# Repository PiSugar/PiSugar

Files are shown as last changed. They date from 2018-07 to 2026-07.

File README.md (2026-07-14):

<p align="center">
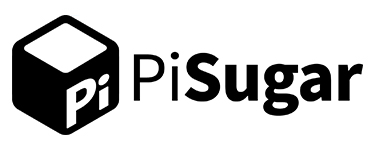
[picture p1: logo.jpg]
  
</p>

English | [简体中文](./README.zh-CN.md)

#### Hackaday Project Page

https://hackaday.io/project/164733-pisugar-battery-for-raspberry-pi-zero

#### Official Store:

<a href="https://shop.pisugar.com/?ref=github" target="_blank">PiSugar Kitchen</a> 

#### Tindie Store



#### PiSugar3 on Amazon:
<a href="https://www.amazon.com/dp/B0H5JMWJJ6" target="_blank">US</a> 
<a href="https://www.amazon.co.uk/dp/B09QS12N1W" target="_blank">UK</a> 
<a href="https://www.amazon.de/dp/B09QS12N1W" target="_blank">Germany</a> 
<a href="https://www.amazon.fr/dp/B09QS12N1W?ref=myi_title_dp" target="_blank">France</a> 
<a href="https://www.amazon.com.au/dp/B0CXX7X9X7" target="_blank">Australia</a> 
<a href="http://www.amazon.co.jp/dp/B09QRQPWYC?ref=myi_title_dp" target="_blank">Japan</a> 

#### PiSugar3 Plus on Amazon:
<a href="https://www.amazon.com/dp/B0H51CW3Q5" target="_blank">US</a> 
<a href="https://www.amazon.co.uk/dp/B09QRS666Y" target="_blank">UK</a> 
<a href="https://www.amazon.de/dp/B09QRS666Y" target="_blank">Germany</a> 
<a href="https://www.amazon.fr/dp/B09QRS666Y?ref=myi_title_dp" target="_blank">France</a>  
<a href="https://www.amazon.com.au/dp/B09QRS666Y?ref=myi_title_dp" target="_blank">Australia</a> 
<a href="https://www.amazon.co.jp/dp/B09QRY2KNG?ref=myi_title_dp" target="_blank">Japan</a> 

#### PiSugar3 Air on Amazon:
<a href="https://www.amazon.com/dp/B0H4Z5XK7F" target="_blank">US</a> 

#### PiSugar2 on Amazon:
<a href="https://www.amazon.com/dp/B08D678XPR" target="_blank">US</a> 
<a href="https://www.amazon.co.uk/dp/B08D678XPR" target="_blank">UK</a> 
<a href="https://www.amazon.de/dp/B08D678XPR" target="_blank">Germany</a> 
<a href="https://www.amazon.fr/dp/B08D678XPR" target="_blank">France</a>
<a href="https://www.amazon.com.au/dp/B08D678XPR?ref=myi_title_dp" target="_blank">Australia</a>  
<a href="https://www.amazon.co.jp/dp/B08D678XPR" target="_blank">Japan</a>

#### PiSugar2 Pro(Plus) on Amazon:
<a href="https://www.amazon.com/dp/B08D8PPCKN" target="_blank">US</a> 
<a href="https://www.amazon.co.uk/dp/B08D8PPCKN" target="_blank">UK</a> 
<a href="https://www.amazon.de/dp/B08D8PPCKN" target="_blank">Germany</a> 
<a href="https://www.amazon.fr/dp/B08D8PPCKN" target="_blank">France</a> 
<a href="https://www.amazon.com.au/dp/B08D8PPCKN?ref=myi_title_dp" target="_blank">Australia</a>  
<a href="https://www.amazon.co.jp/dp/B08D8PPCKN" target="_blank">Japan</a> 

#### PiSugarS on Amazon:
<a href="https://www.amazon.com/dp/B0H4VCS6CF" target="_blank">US</a> 

#### PiSugarS Plus on Amazon:
<a href="https://www.amazon.com/dp/B0H4TY3KCN" target="_blank">US</a> 

#### Product Wiki

[PiSugar Wiki](https://docs.pisugar.com)

## Why We Make PiSugar

In the last few months, we have been working on projects base on Pi zero. It always comes to my mind that why we choose this tiny thing, to build a new portable product.

We believe perfect size will completely change the way we think.
We also believe in delicacy and better experience, which are essential for electronic circuit board.

After trying a number of power supply solutions, we found that none of them is elegent enough.
So we decide make it by ourselves. 

We call it PiSugar PowerPack — a power module specially designed for raspberry pi.

PiSugar Demo

## Features

#### Perfect Size
The sizes of circuit board and bettery perfectly match raspberry pi zero. You can easy put your prototypes in small cases.

#### Easy to Install
Install in one minute. No need for welding. Friendly for beginners.

#### USB Charging
Charge via micro USB port. Also you can charge when it is running a raspberry pi zero.

#### On-board Switch
One tap to turn on, dual taps to turn it off. No need to detach.

#### Place It Anywhere
With iron sheets inside, you can place your pi zero anywhere with magnet.

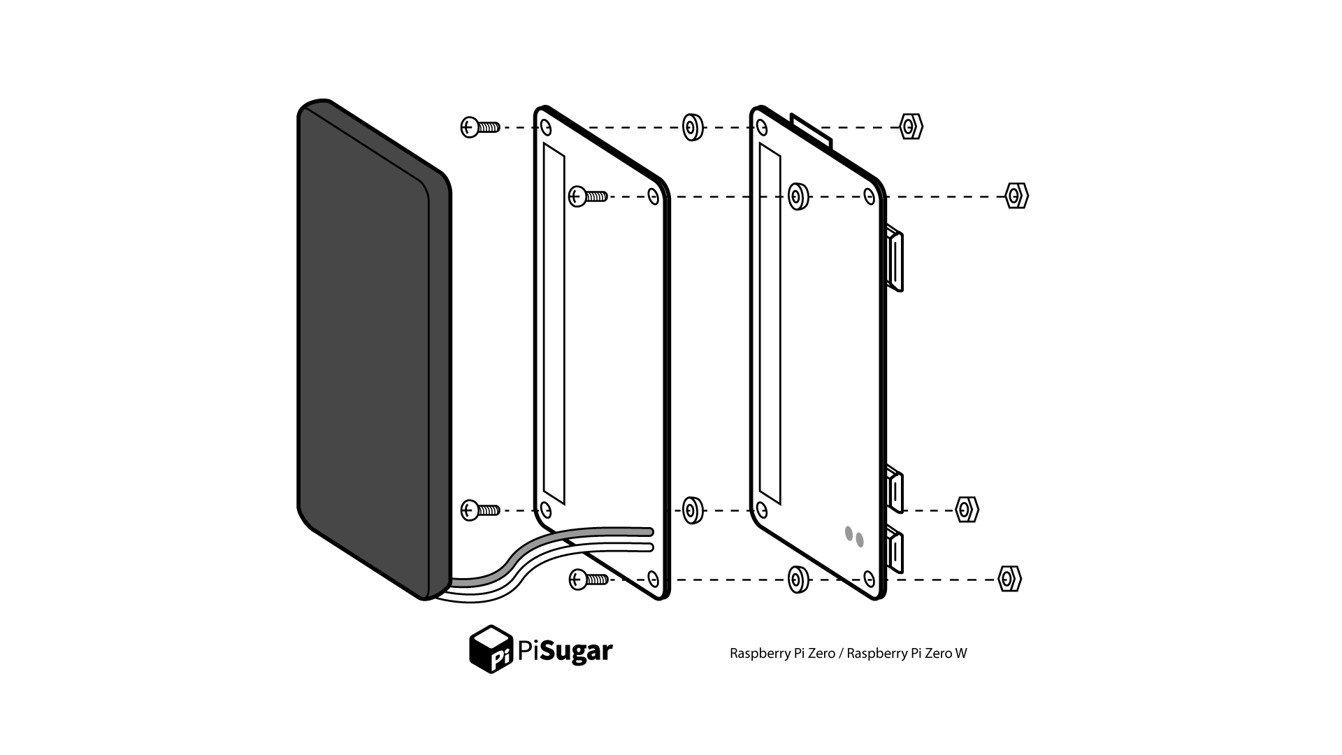
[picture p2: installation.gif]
Easy to install

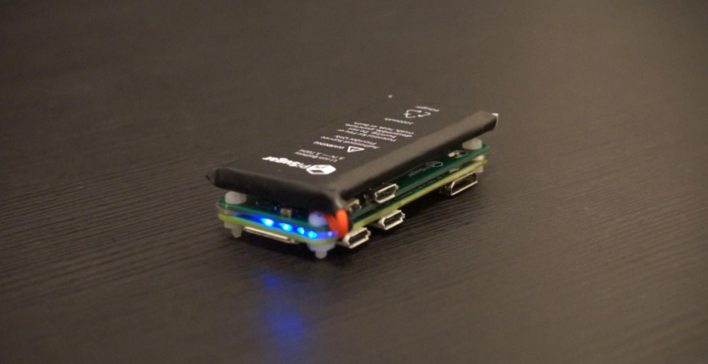
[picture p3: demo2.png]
PiSugar Demo


## PiSugar Case

Link to PiSugar Case: https://github.com/PiSugar/PiSugar/tree/master/model

Link to PiSugar2 Case: https://github.com/PiSugar/PiSugar/tree/master/model2

Link to PiSugar3 Case: https://github.com/PiSugar/PiSugar/tree/master/model3

Link to PHAT Caps: https://github.com/PiSugar/pisugar-case-pihat-cap

PiSugar Caps

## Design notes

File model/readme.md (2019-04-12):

# PiSugar Case

PiSugar Logo

#### PiSugar Case 3D-printed Models

[简体中文](https://github.com/PiSugar/PiSugar/tree/master/model/readme.zh-CN.md) | English

Files included:

- pisugar_case_shell （use with 900mAh battery）

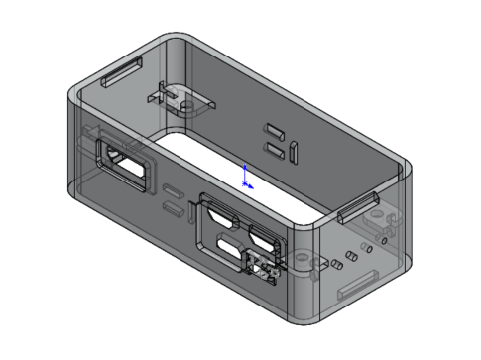
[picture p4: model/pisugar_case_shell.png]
pisugar_case_shell


- pisugar_case_shell_xl （use with 1200mAh battery）

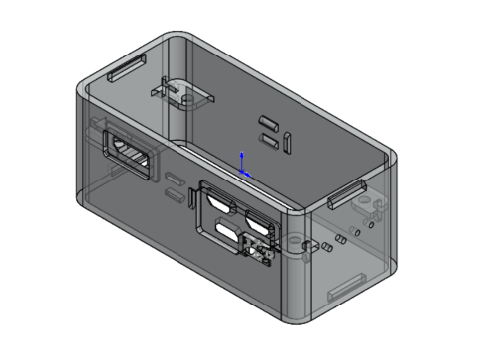
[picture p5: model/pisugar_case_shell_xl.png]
pisugar_case_shell_xl


- pisugar_case_common_cap （common cap for both top and bottom）

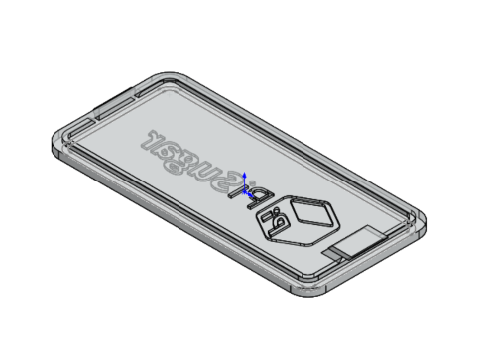
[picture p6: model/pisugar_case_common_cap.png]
pisugar_case_common_cap


- pisugar_case_pin_cap （cap with GPIO opening）

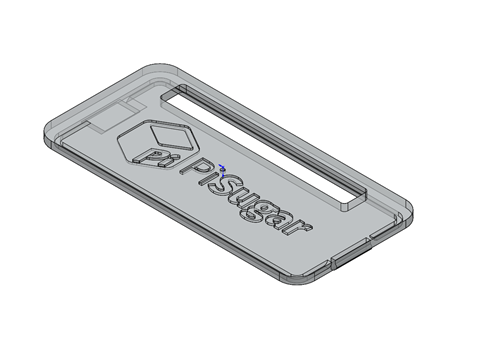
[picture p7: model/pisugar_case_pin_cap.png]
pisugar_case_pin_cap


- pisugar_case_top_cap （cap with 2 screw holes, should use with 1cm standoff）

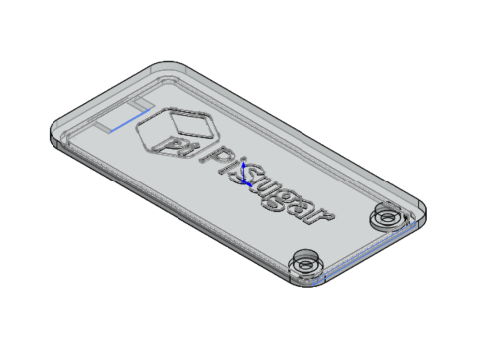
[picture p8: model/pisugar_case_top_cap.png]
pisugar_case_top_cap


- pisugar_case_button （single button）

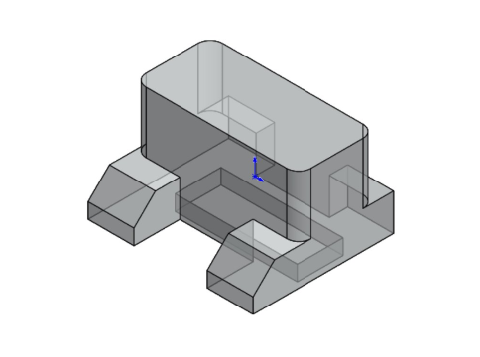
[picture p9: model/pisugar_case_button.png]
pisugar_case_button


- pisugar_case_button_comp (8 buttons)

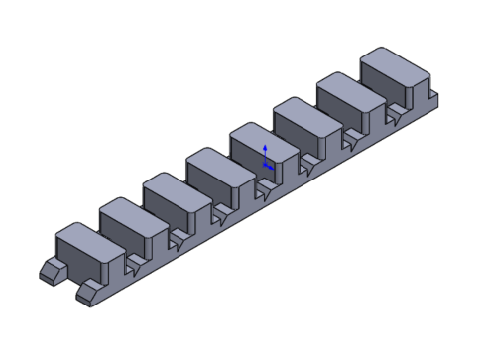
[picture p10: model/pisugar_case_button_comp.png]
pisugar_case_button_comp


Note: Recommand minimum thickness > 0.5mm. Raw files are edited in Solidworks 2018

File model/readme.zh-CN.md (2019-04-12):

# PiSugar Case

PiSugar Logo

#### PiSugar Case 3D打印模型文件

简体中文 | [English](https://github.com/PiSugar/PiSugar/tree/master/model/readme.md)

文件包括

- pisugar_case_shell （900mAh版本的边框）

pisugar_case_shell

- pisugar_case_shell_xl （1200mAh版本的边框）

pisugar_case_shell_xl

- pisugar_case_common_cap （上下通用卡扣盖子）

pisugar_case_common_cap

- pisugar_case_pin_cap （带排针开口的盖子）

pisugar_case_pin_cap

- pisugar_case_top_cap （带螺丝孔的上盖，需配合1cm的螺丝柱使用）

pisugar_case_top_cap

- pisugar_case_button （单个按钮）

pisugar_case_button

- pisugar_case_button_comp (8个按钮联排，可打印出来再掰开使用)

pisugar_case_button_comp

注意：建议材料最低厚度支持0.5mm。模型文件请使用solidworks 2018进行编辑。

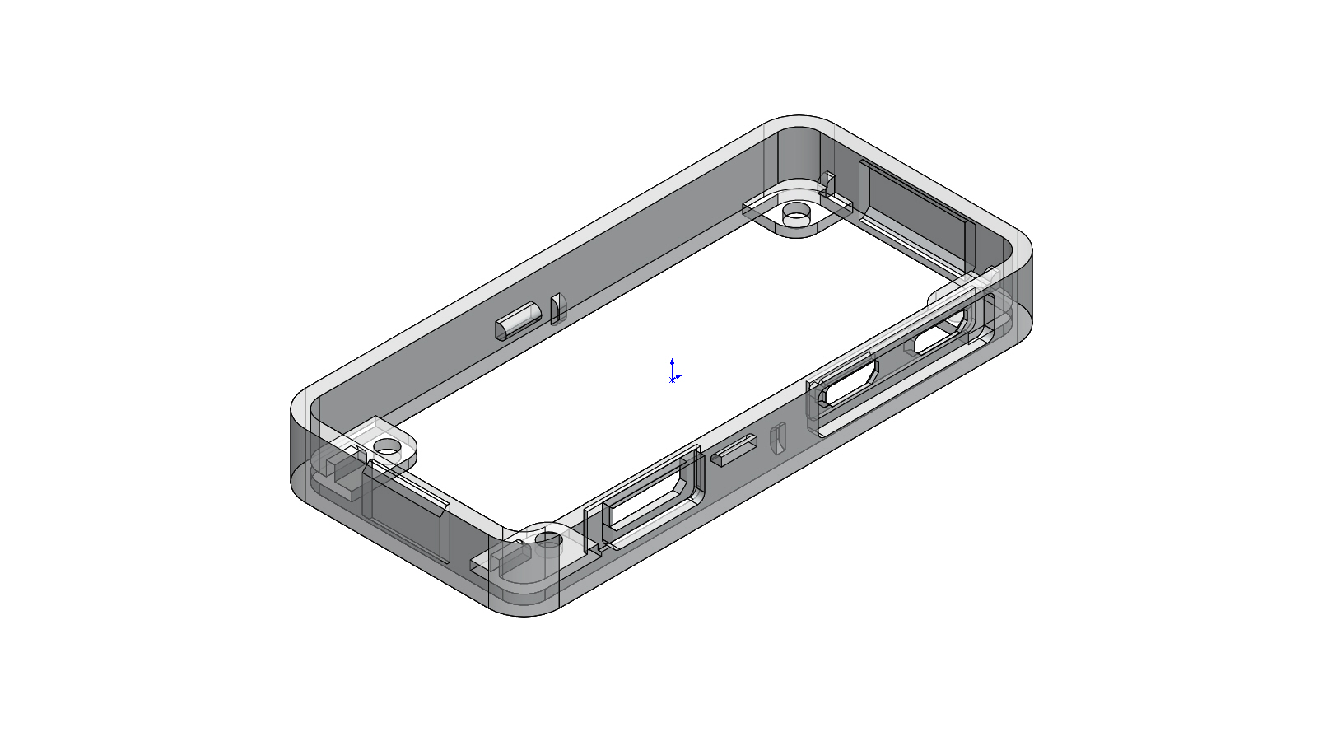
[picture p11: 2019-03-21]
model/pisugar_thin_nobatt_shell.JPG

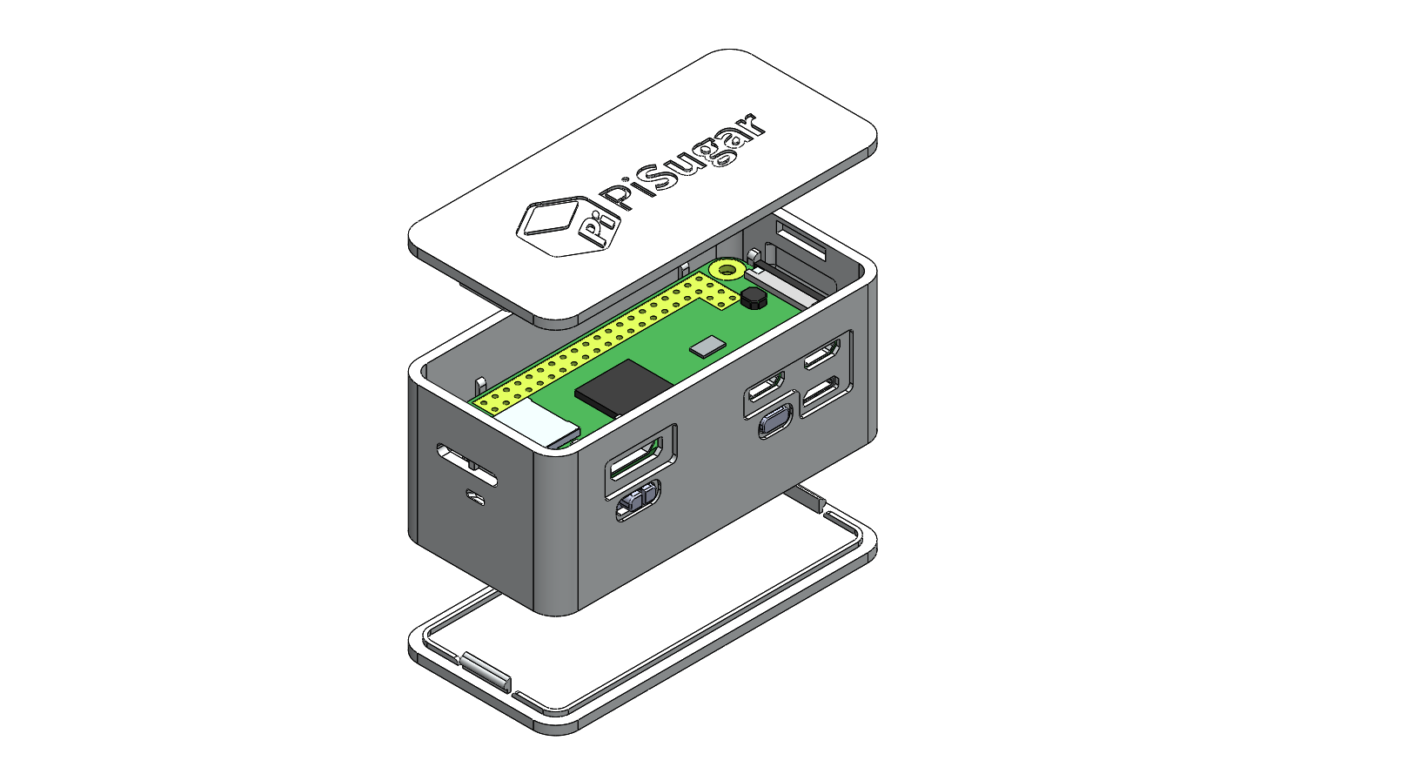
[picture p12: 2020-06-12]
model2/case-ex.PNG

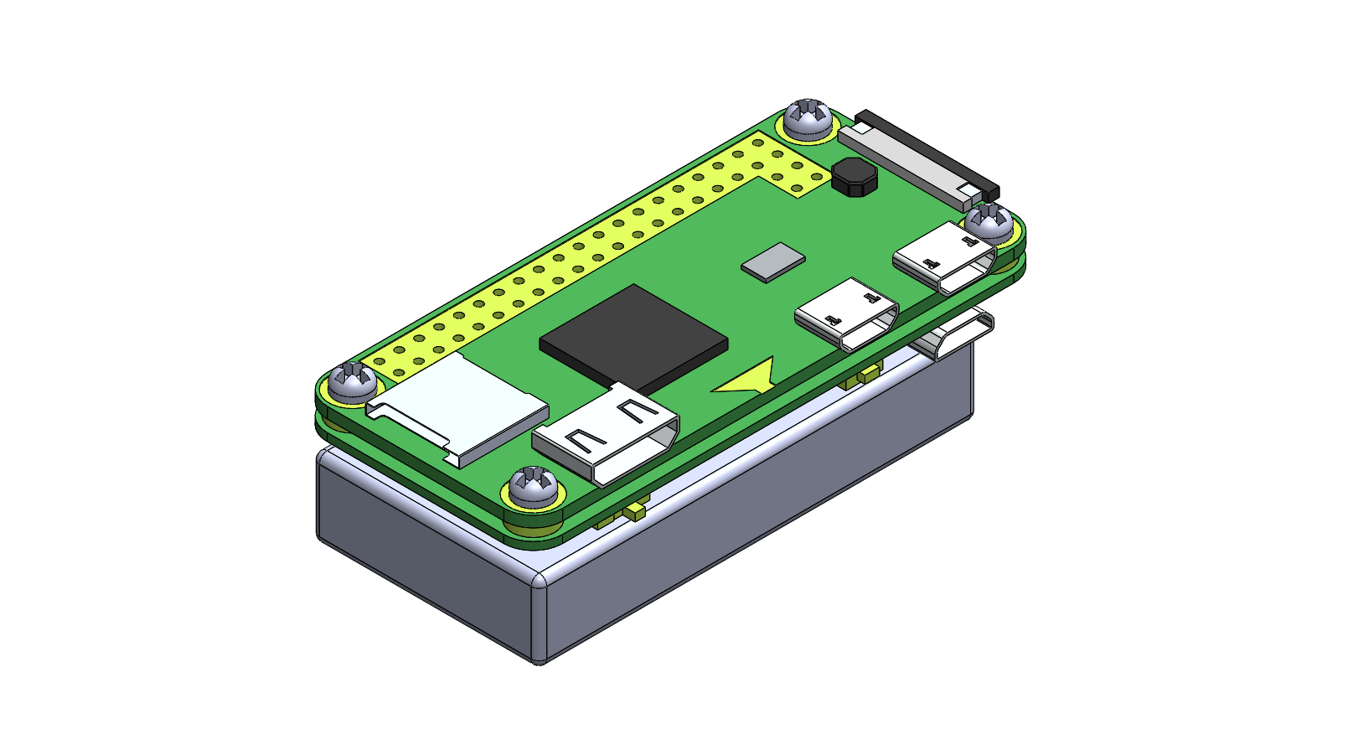
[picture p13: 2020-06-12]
model2/comp2.PNG

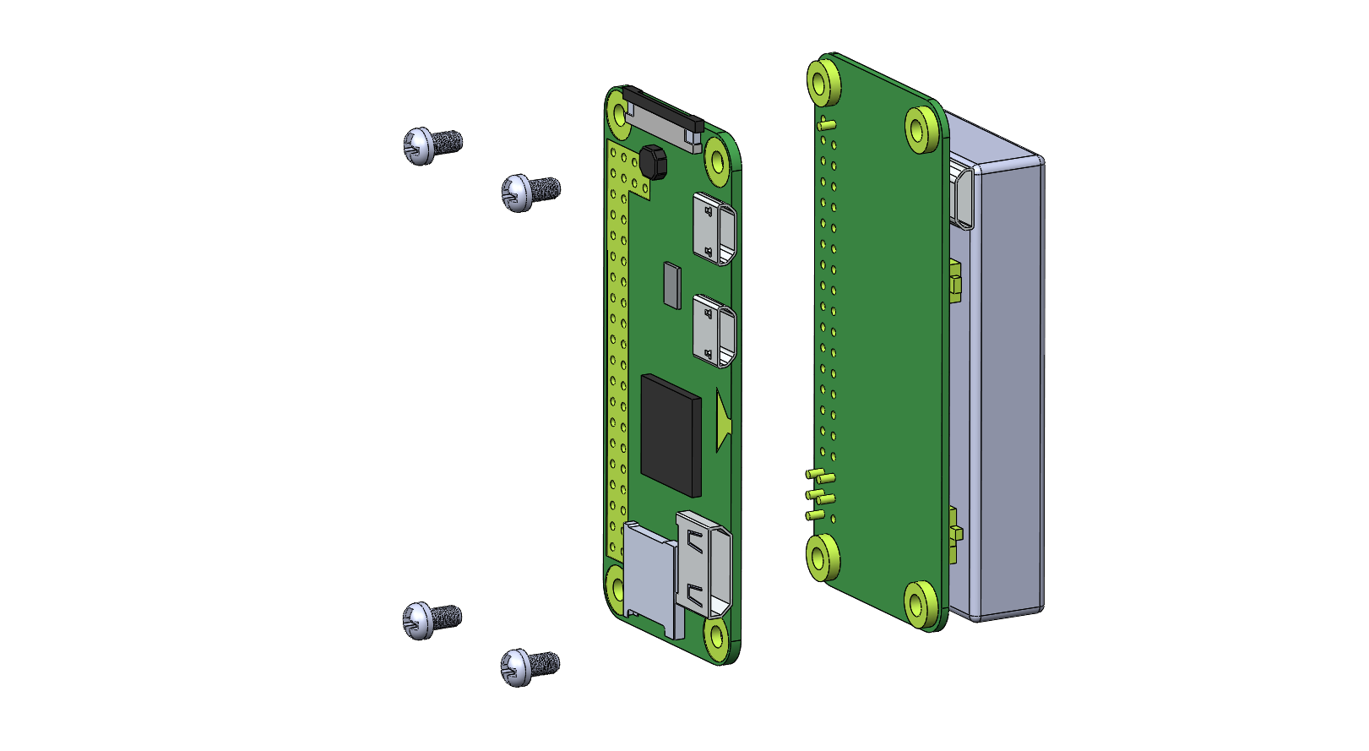
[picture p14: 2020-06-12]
model2/comp2-ex.PNG

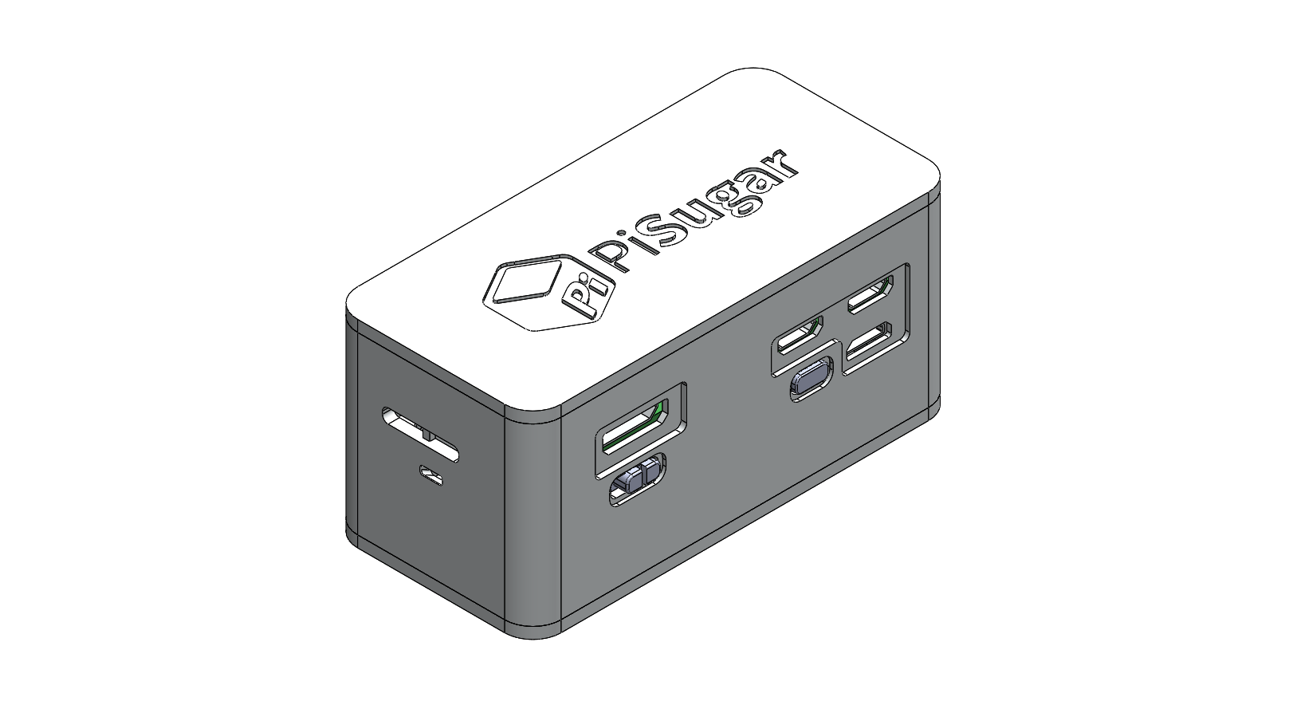
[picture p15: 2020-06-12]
model2/case.PNG

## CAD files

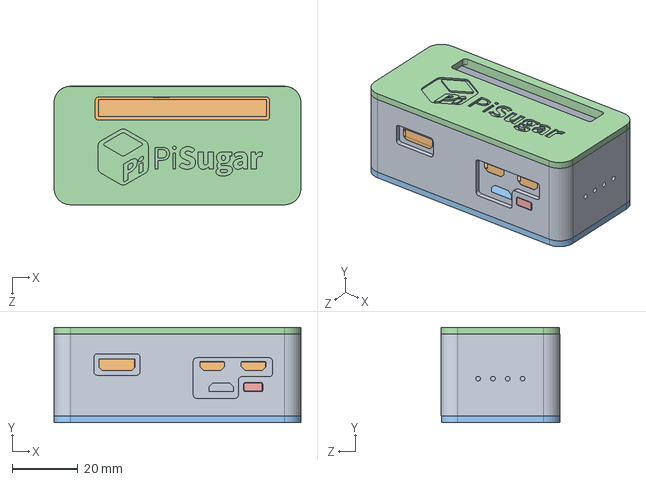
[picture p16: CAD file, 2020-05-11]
model/pisugar_comp.SLDASM
75.0 x 29.0 x 36.0 mm
pisugar_case_common_cap
pisugar_case_pin_cap

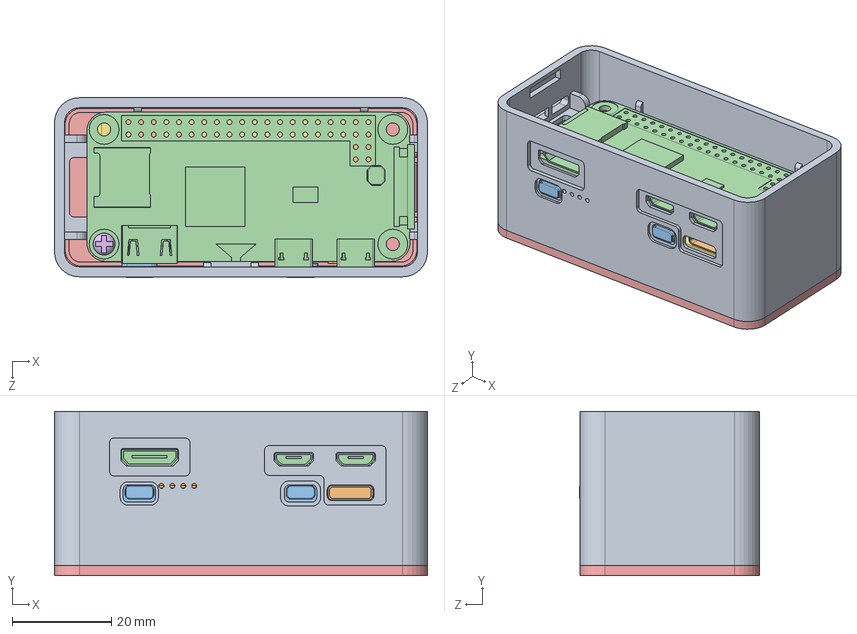
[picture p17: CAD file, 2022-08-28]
model3/comp3.SLDASM
75.0 x 33.0 x 36.1 mm
pisugar3_shell_xl
pisugar3Board
pisugar3_button x 2

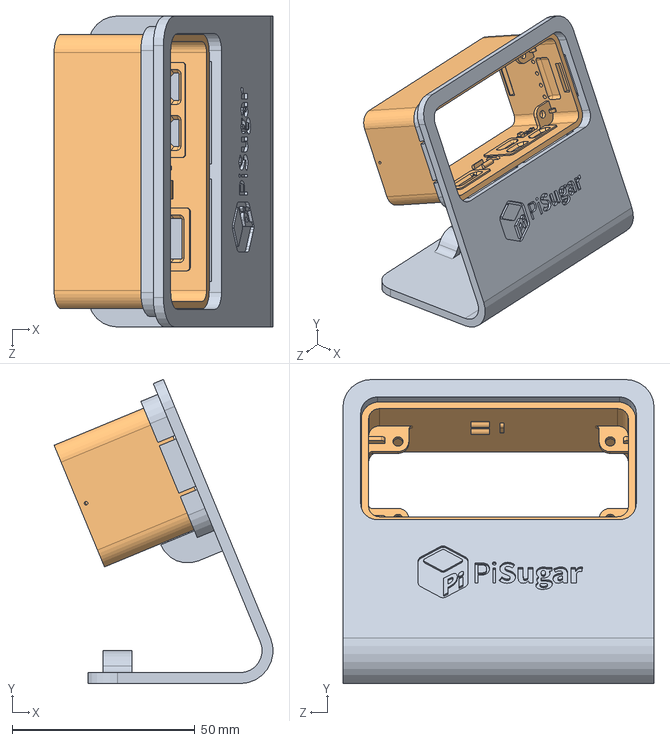
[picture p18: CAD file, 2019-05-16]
model/holder_asm.SLDASM
59.8 x 83.1 x 85.0 mm
pisugar_holder
pisugar_case_shell_xl

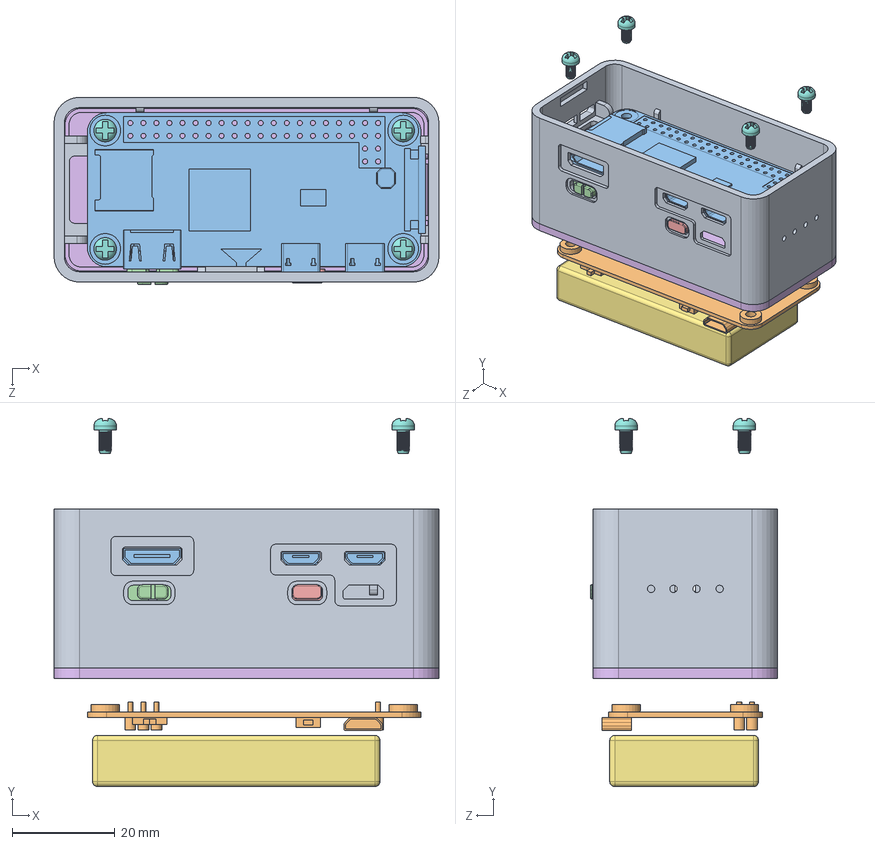
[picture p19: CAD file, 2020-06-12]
model2/comp2-ex.SLDASM
75.0 x 71.7 x 36.5 mm
pisugar2Board
RaspberryPiZeroW
batt-1200
screw x 4

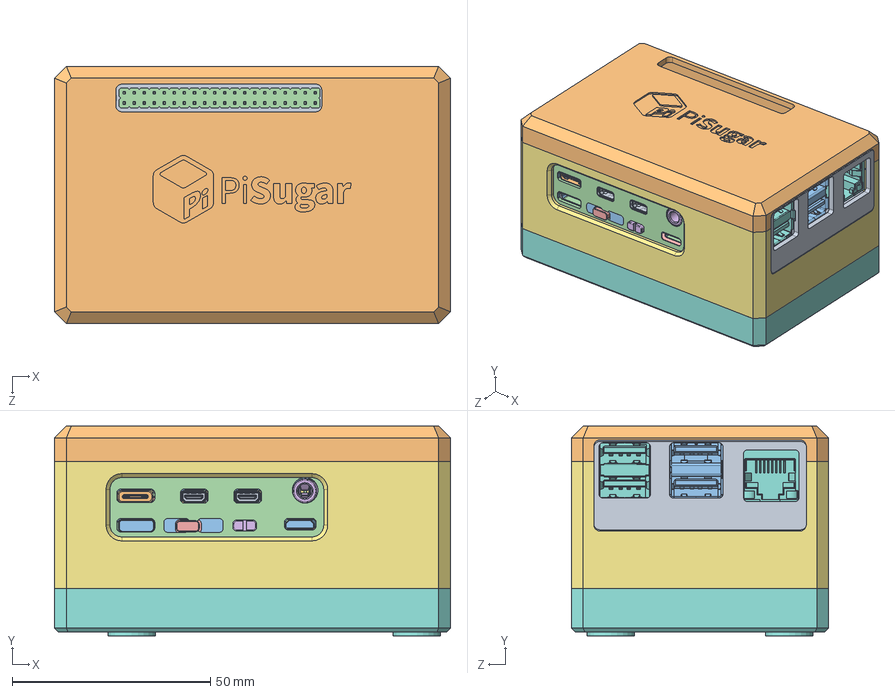
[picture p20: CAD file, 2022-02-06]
model_pro/comp.SLDASM
100.0 x 53.0 x 65.0 mm
PCB, RPi4ModelB
Broadcom BCM2711B0 CPU, RPi4ModelB
2.54 mm DUPONT MALE PIN HEADER, POE, 2X2, RPi4ModelB
2.54 mm DUPONT MALE PIN HEADER, IO, 2X20, RPi4ModelB
Camera Connector, RPi4ModelB
Microphone Plug, RPi4ModelB
Display Connector, RPi4ModelB
Gigabit Ethernet Port, RPi4ModelB
Female Micro HDMI Connector, RPi4ModelB x 2
Female USB Type C Connector, RPi4ModelB
2X USB3.0 PORTS, RPi4ModelB
91D77 D9WHV 778K, 4 GB LPDDR4 SDRAM, RPi4ModelB
Cypress CYW43455 Wireless Module Cover, RPi4ModelB
SD Card Slot, RPi4ModelB
VIA VL805 PCIe USB 3.0 controller, RPi4ModelB
2X USB2.0 PORTS, RPi4ModelB
Broadcom BCM54213PE Gigabit Ethernet Transceiver, RPi4ModelB
MxL7704 Universal PMIC, RPi4ModelB
pisugar3plus
pro_shell
bottom
top
port-panel-4b-3p
usb-panel-4b

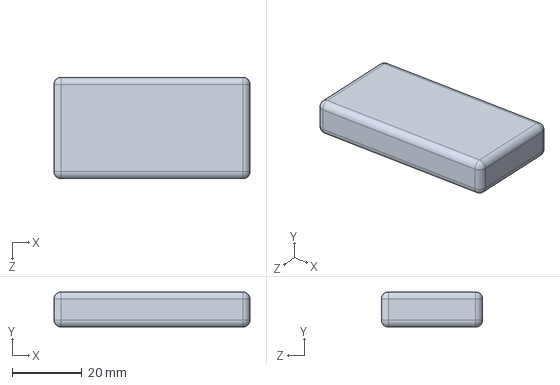
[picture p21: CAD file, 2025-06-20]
model2/batt-1200.SLDPRT
56.0 x 10.0 x 29.0 mm

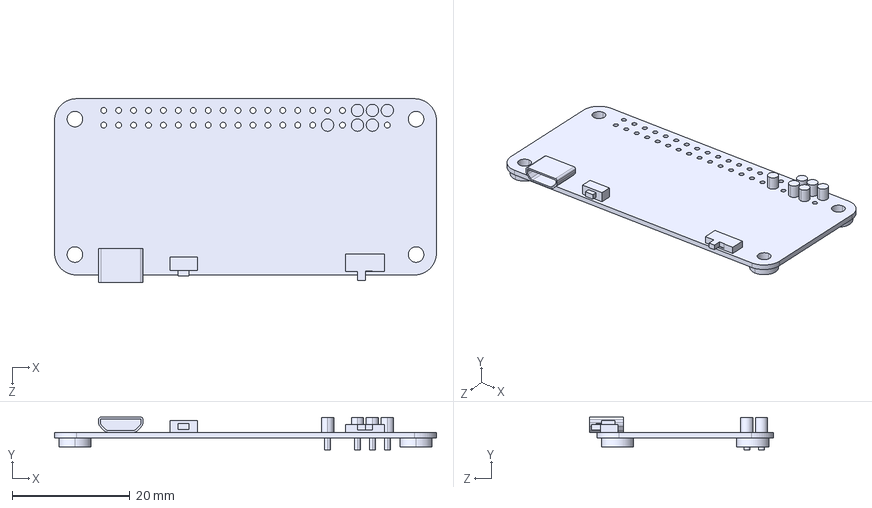
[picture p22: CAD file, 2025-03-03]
model2/step/pisugar2Board.STEP
65.0 x 5.60 x 31.2 mm

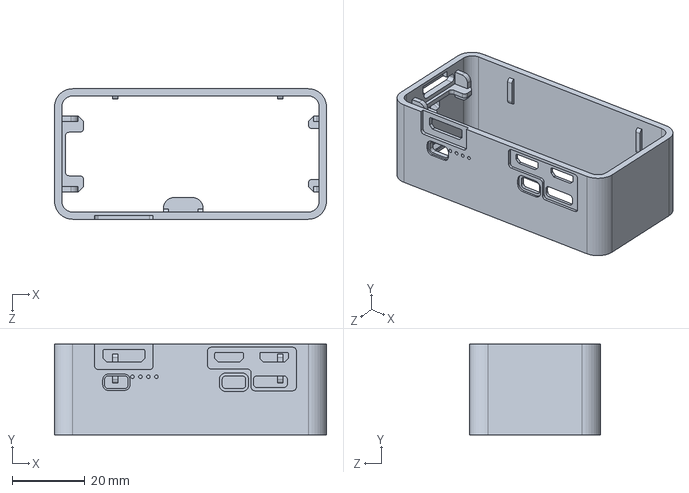
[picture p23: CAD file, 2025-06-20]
model3/pisugar3_thin_shell_xl.SLDPRT
75.0 x 25.0 x 36.0 mm

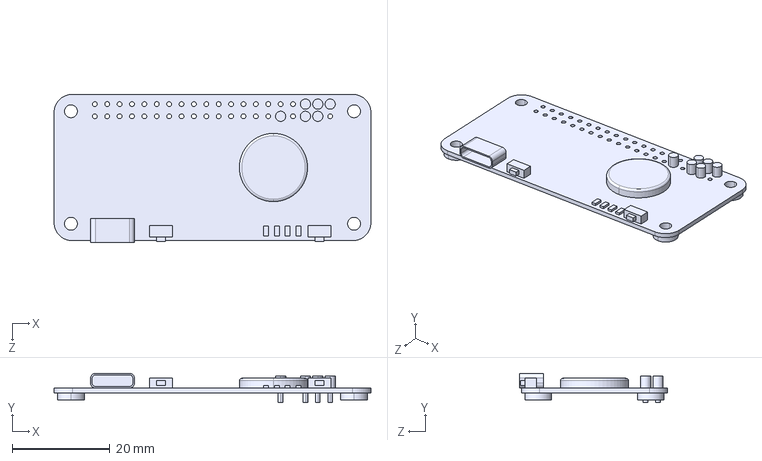
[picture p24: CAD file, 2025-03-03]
model3/step/pisugar3Board.STEP
65.0 x 6.00 x 30.4 mm

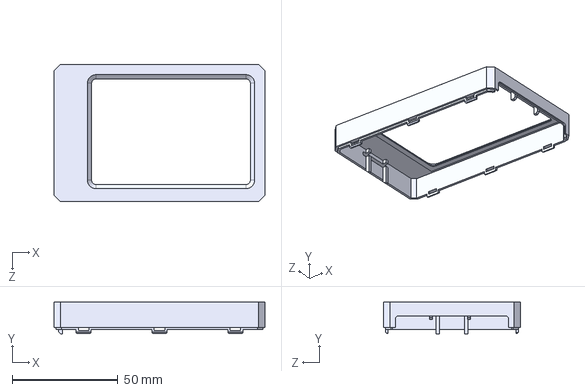
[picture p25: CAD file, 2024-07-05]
model_pro/lid/3.52inch-epaper/3.52inch-epaper-lid.STEP
100.0 x 15.0 x 65.0 mm

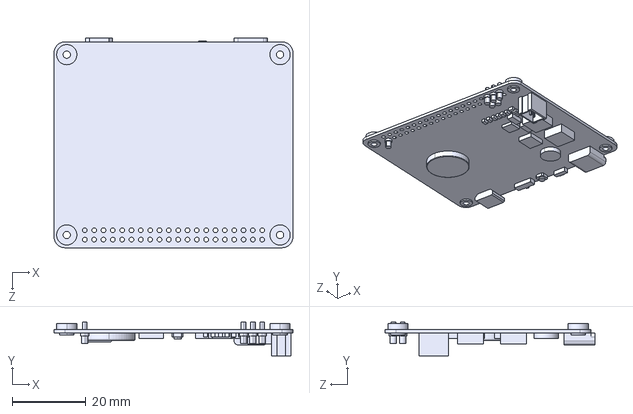
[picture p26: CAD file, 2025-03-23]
model_pro/pisugar2pro.STEP
65.0 x 9.22 x 57.0 mm

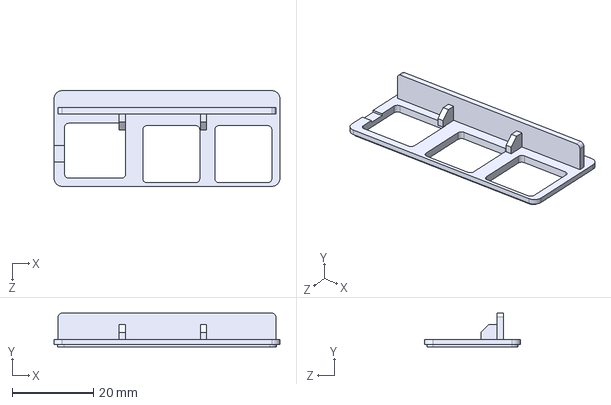
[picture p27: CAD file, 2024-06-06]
model_pro/step/usb-panel-3b.STEP
55.5 x 8.30 x 23.5 mm

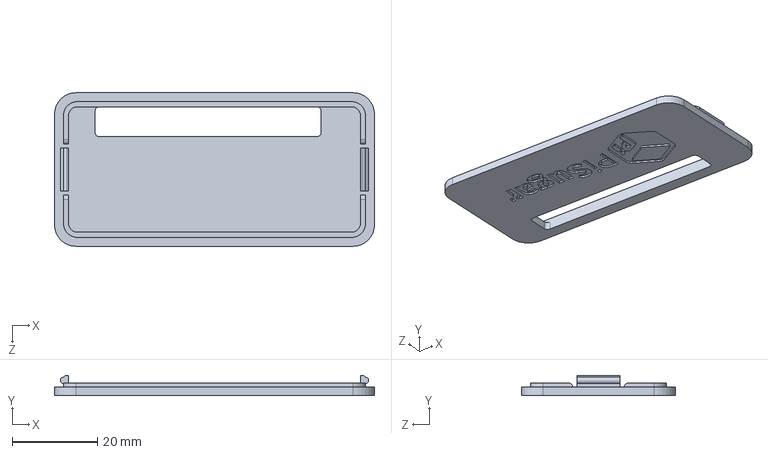
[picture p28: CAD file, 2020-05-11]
model/pisugar_case_pin_cap.SLDPRT
75.0 x 4.80 x 36.0 mm

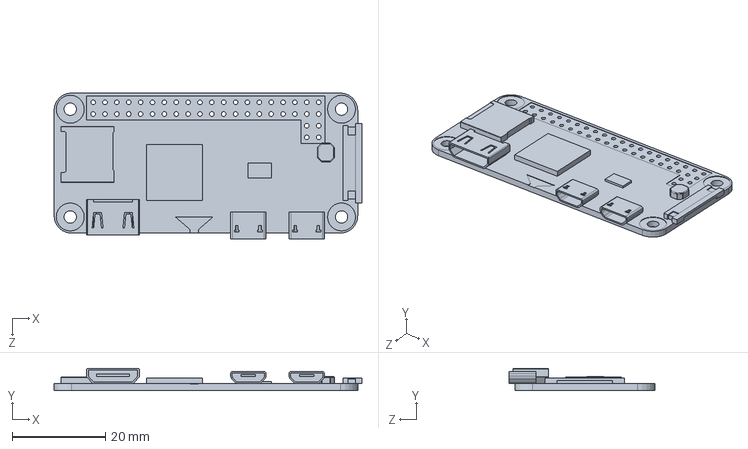
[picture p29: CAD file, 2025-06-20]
model3/RaspberryPiZeroW.SLDPRT
65.9 x 4.80 x 31.2 mm

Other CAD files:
model2/comp2.SLDASM
model3/step/pisugar_case_common_cap.STEP
model_pro/lid/3.52inch-epaper/3.52inch-epaper.SLDPRT
model_pro/pisugar3plus.STEP
model/battery900.SLDPRT
model/glass.SLDPRT
model/pisugar.SLDPRT
model/pisugar_bw2.dwg
model/pisugar_case.SLDPRT
model/pisugar_case_all.SLDPRT
model/pisugar_case_button.SLDPRT
model/pisugar_case_button.STL
model/pisugar_case_button_comp.SLDPRT
model/pisugar_case_button_comp.STL
model/pisugar_case_pin_cap.STL
model/pisugar_case_shell.SLDPRT
model/pisugar_case_shell.STL
model/pisugar_case_shell_xl.SLDPRT
model/pisugar_case_shell_xl.STL
model/pisugar_case_thin_shell.SLDPRT
model/pisugar_case_thin_shell.STL
model/pisugar_case_thin_shell_xl.SLDPRT
model/pisugar_case_thin_shell_xl.STL
model/pisugar_case_top_cap.SLDPRT
model/pisugar_case_top_cap.STL
model/pisugar_holder.SLDPRT
model/pisugar_holder.STL
model/pisugar_nobatt_shell.SLDPRT
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

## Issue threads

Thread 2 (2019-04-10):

Where to buy ?

AntoineTurmel, 2019-04-10:
Will this board/battery be sell someday ?

JdaieLin, 2019-04-10:
Hi Antoine, yes it's current available in China. If everything goes fine, you will be able to buy it on Amazon US soon in this month.

AntoineTurmel, 2019-04-10:
Nice ! I look forward it then :)
How does it compete with JuiceBox Zero board ?

JdaieLin, 2019-04-10:
I think the main purposes of designing PiSugar are portability and productization. We came out this idea when we were creating a portable device. In fact, there are solutions like JuiceBox supplying power through gpio pins, but they take too much space. We really need to put the zero and battery into a small box (P.S. We don't know how to model at that time...). So after we created the battery, we build the cases for the battery and also, for other piHats. I think it's important if you send a pi project, as a gift, to a friend who knows little about developing. I hope it looks like a complete product : )

AntoineTurmel, 2019-04-10:
Ok thanks for the explanation 👍

palradu, 2019-04-13:
Q: Is there any way that we could import it from China? Is it available on Aliexpress, Gearbest etc.? I'm asking because I doubt that we'll be able to get it in Europe through Amazon :(

JdaieLin, 2019-04-14:
> Q: Is there any way that we could import it from China? Is it available on Aliexpress, Gearbest etc.? I'm asking because I doubt that we'll be able to get it in Europe through Amazon :(

I see. If we can solve the shipping problem, I think it can will be available on Tindie or Aliexpress too.
In fact, I had tried to mail one of this from the Netherlands to a friend in Germany using postNL, but it didn't arrive... I need some time to find a reliable way to ship this oversea.

palradu, 2019-04-14:
PostNL should work alright. I ordered online quite a few times and more often than not, the items were shipped through PostNL. The only problem in Europe, with a board like this, is the battery. The EU has strict rules when it comes to the import of batteries from overseas and that could make it so the package gets confiscated at customs. A good read on this is here: https://andrewminalto.com/shipping-batteries/ . If there were a way to add a battery plug to the board so we could use locally available batteries, that would simplify the whole process. I'm thingking of a connector like this: https://www.sparkfun.com/products/9749 . All we'd need then would be the battery specs, so we could buy the right type of battery.

JdaieLin, 2019-04-14:
You are right. Sadly I sent a pi zero and a keyboard with the battery... We had considered about battery plug but it takes much space. If the shipping problem exist, maybe we should reconsider about a plug version.

palradu, 2019-04-14:
Indeed, a plug would take up some space, but the advantage is that you could ship the board anywhere in the world then. You could find the smallest plug that works with that type of battery and if it's not that widespread, when you send out the board, you could send the female part of the plug as an extra and we'd just need to attach it to the battery leads with screws. I've been looking for a board like this for a while, and I couldn't find one. And if I were to make one myself, I couldn't fit it in a case. And since I don't know how to 3D model, I couldn't create the case that I needed. Your implementation is perfect and I can't wait to get my hands on the board. Even without the plug. Even if I have to solder the battery leads myself :)

leperjulien, 2019-04-16:
Wow just found about your project on hackaday which led me here :D And you can me add me up to the list of people located in Europe (FR) and who are really interested in trying your board with a RPI Zero W ! Desing is awesome btw

JdaieLin, 2019-04-23:
> Indeed, a plug would take up some space, but the advantage is that you could ship the board anywhere in the world then. You could find the smallest plug that works with that type of battery and if it's not that widespread, when you send out the board, you could send the female part of the plug as an extra and we'd just need to attach it to the battery leads with screws. I've been looking for a board like this for a while, and I couldn't find one. And if I were to make one myself, I couldn't fit it in a case. And since I don't know how to 3D model, I couldn't create the case that I needed. Your implementation is perfect and I can't wait to get my hands on the board. Even without the plug. Even if I have to solder the battery leads myself :)

Where do you usually buy batteries from? Do they have plug already soldered? If so, maybe we should choose a plug type that is widely used.

palradu, 2019-04-23:
Yes, most of them already have the plug soldered on. In Romania, we can get them from local distributors, such as: https://www.robofun.ro/surse_de_alimentare/acumulatori , https://www.optimusdigital.ro/ro/296-acumulatori-lipo or https://www.conexelectronic.ro/ro/417-acumulatori and we can also order from within the EU, Pimoroni being a good example: https://shop.pimoroni.com/collections/prototyping/power . All links point to the available battery packs, so you can maybe get an idea about what would be the best plug to choose.

JdaieLin, 2019-04-23:
Apparently I had never heard of these websites until today... Many thanks!

JdaieLin, 2019-04-23:
> Wow just found about your project on hackaday which led me here :D And you can me add me up to the list of people located in Europe (FR) and who are really interested in trying your board with a RPI Zero W ! Desing is awesome btw

Yeah I notice that you are all from Europe. I will let you know once we solve the shipping problem. Thanks!

palradu, 2019-04-23:
> Apparently I had never heard of these websites until today... Many thanks!

You're welcome! I hope the links will help :)

JdaieLin, 2019-05-04:
Hi everyone. I'm glad to inform you that PiSugar is now available on amazon!

https://www.amazon.com/dp/B07R7Z2334

For the shipping problems, we have found a reliable shipping agent and tried to send the products(including boards and batteries) to Europe countries(NL, FR, GE). It takes about 10 days and all of the packages are successfully received.

JdaieLin, 2019-05-05:
I just know that there will be extra shipping fee when buying things from Amazon US in Europe. Therefore we will soon put them on Amazon Europe, too. Maybe the day after tomorrow. I'll let you know asap.

palradu, 2019-05-05:
This is amazing news! Thank you so much! I can't wait for it to be available on Amazon Europe, so I can get my hands on it :D

JdaieLin, 2019-05-08:
Updated!

https://www.amazon.es/dp/B07RLZ8Q3M
https://www.amazon.it/dp/B07RFVDG3P
https://www.amazon.fr/dp/B07RHX3P9Z
https://www.amazon.de/dp/B07RHWYMTJ
https://www.amazon.co.uk/dp/B07RDNT8CY

JdaieLin, 2019-05-14:
> This is amazing news! Thank you so much! I can't wait for it to be available on Amazon Europe, so I can get my hands on it :D

It turns out that Amazon doesn't have .ro site. So consider buying it from amazon.de. We had told our seller friends to lower the shipping fee in .de for eastern Europe countries.

palradu, 2019-05-21:
> > This is amazing news! Thank you so much! I can't wait for it to be available on Amazon Europe, so I can get my hands on it :D
>
> It turns out that Amazon doesn't have .ro site. So consider buying it from amazon.de. We had told our seller friends to lower the shipping fee in .de for eastern Europe countries.

Yup, we still don't have an Amazon.ro site :( But yes, the .de or .es is where I will buy from :) Thank you so much for this! :)

AntoineTurmel, 2019-05-27:
I received mine today 👍

autrion, 2020-01-17:
Has anyone had luck ordering from Amazon? I have ordered from Germany and the first package was lost according to the tracking info. Then the vendor send it again but I have never recieved anything, not even a second tracking number! Slowly I have given up and are looking for an alternative.

StevenMercurio, 2020-02-28:
Anyone have links to where I can buy a case?  Don't have a 3D printer or know anyone who does (unless there is some cloud based 3D printing service I don't know about yet)

JdaieLin, 2020-03-02:
Hi Steven,

you can buy case along with PiSugar battery on Tindie.com. Also recommended a cloud based 3D printing service: http://www.wenext.hk

------------------ Original ------------------
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

JdaieLin, 2020-03-09:
> Has anyone had luck ordering from Amazon? I have ordered from Germany and the first package was lost according to the tracking info. Then the vendor send it again but I have never recieved anything, not even a second tracking number! Slowly I have given up and are looking for an alternative.

Hi autrion,

please contact pisugar.zero@gmail.com for the order issue, thanks!

GSVNoFixedabode, 2021-01-03:
Hi, is there any update on making this available via AliExpress? I tried the Amazon listing but it doesn’t allow shipping to New Zealand. I’d add my vote to a batteryless version!

JdaieLin, 2021-03-06:
> Hi, is there any update on making this available via AliExpress? I tried the Amazon listing but it doesn’t allow shipping to New Zealand. I’d add my vote to a batteryless version!

You can try Tindie.com

Closed 2024-09-11.

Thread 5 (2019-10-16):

Broken micro-usb port - PiSugar V1

mlinton, 2019-10-16:
The micro-usb port broke off of the pcb, and I'd like to re-attach it or find out where the 5v and ground from the USB port can be soldered elsewhere on the board.

JdaieLin, 2019-10-22:
Hi, mlinton. Please contact pisugar.zero@gmail.com to send you a replacement board. It will be easier to re-attach the battery than a usb port.

dadav, 2019-11-02:
Hello, i got the same problem. Will contact you too

Closed 2021-03-06.

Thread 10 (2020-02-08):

Unespected behaviour (or dumb user, I don't know...)

mickymix, 2020-02-08:
I've attached my 1200mah PiSugar to my Pi0W which I use in the car.

I would like to use it as a backup power for the Pi0w when the car removes power from the 12V circuit some minutes after having closed it.

Since I only have one USB slot available, I'm using a Y cable to split power and data (https://www.amazon.it/gp/product/B071H54CKS).
I've attached the data side to the USB on the Pi0w and the power side to the PiSugar.

The strange thing that happens is that, whenever the car removes the power from the USB port, the Pi0w powers off, as the PiSugar, while being charged, shuts down too...

I've tried connecting the power side of the Y cable to the Pi0w, but this doesn't charge the PiSugar, so it only lasts until there is power in the battery...

Is this an intended behaviour ?
Where is my error ?

JdaieLin, 2020-02-08:
Hi Micky,
I cannot open the link: https://www.amazon.it/gp/product/B071H54CKS=
had you met this problem while using other USB cable?

JdaieLin, 2020-02-08:
Connecting the power side of the Y cable to the Pi0w will not charge the PiSugar. It's normal behavior.

I'm wondering if the cable can charge the PiSugar along without the data side connecting to the pi0w. Not sure how it actually split power and data.

mickymix, 2020-02-08:
Hi Jdaie,
sorry, the link for cable was wrong (added one character by mistake...).

Anyway, the cable was suggested by other users using the Pi0w for my same needs on this other GH project: https://github.com/marcone/teslausb
The cable has been perfectly working before I attached the PiSugar to my Pi0w, so I believe it might not be the problem... (will check anyway getting 12V with another cable elsewhere...).

The cable is capable of charging the PiSugar, as when car's 12V is present, Pi and PiSugar are working, and PiSugar is always well charged (4 leds full on...).
Anyway when the car cuts 12V, the PiSugar switches off, while still having fully loaded battery.

Indeed, if I manually switch the PiSugar on, it powers the Pi correctly.

It seems that when power disappears from the cable, this makes the PiSugar switch off too, and this seems strange to me, unless this might be "cable-related".

Could the PiSugar behave differently when incoming power is removed gradually or suddenly ?
Should the PiSugar be already on before adding incoming power to have it stay on when it is removed ?
I'll try some more cable and switch-on combinations as soon as I can, but just wanted to investigate if there is anything I should know before.

Thank you for your help.

JdaieLin, 2020-02-08:
It's strange that the PiSugar switches off. Normally it will keep on when removing the power, switching power source from USB to battery. And the pi0w will reboot during the switching, rather than turning off.

JdaieLin, 2020-02-08:
There is no need to turn on PiSugar before adding incoming power. It doesn't matter.

mickymix, 2020-02-08:
Thank you for your fast reply.

I also had the chance to make a couple of checks with the cables.

I discovered that this strange behaviour ALWAYS happens with the Y splitter cable: either when I remove the cable from the supply side, either when I remove the cable on the power exit side...
So I thought the problem was the cable indeed...

Tried working without the splitter, and I've been successfull for a couple of minutes... :-(

Not more than a couple of minutes, because on the first 3 or 4 trials I had success: the PiSugar did not switch off and continued supplying power to the pi0w, which did not reboot...

But after few minutes I did remove the power coming from the car and it happened again...

FYI, the PiSugar was not completely charged, but was around 50% (two leds lit)

I think I'll need to further investigate, because the above tests were made without waiting for the pi0w to complete bootstraps (just looking at the working green led...).
To be more precise I think I'll need to have some more spare time.

I'll let you know.

JdaieLin, 2020-02-08:
There is no difference when removing the cable on supply side or power exit side.
On and off is decided by the power management chip on board.

1. I am not sure the cable has strictly split the power and data, perhaps the data side also has power output? If so, then the PiSugar will work inside a close circus which will leads to unknown result.
2. maybe the chip is somehow damaged thus it behaves strangely.

I suggest you test it on other simple usb cables to see whether it behaves the same.

HynekPetrak, 2020-04-07:
Hi, I have a rpi0w with a waveshare eink 2.13" V2 display attached. Just received my sugar from tindie and mounted. I charged the pisugar to 4 blue leds. I observe two things:
- as soon as I disconnect the pisugar from the USB power chager, the rpi0w reboots. Everytime, tested with two cables.
- when I'm connected to a USB port on rpi0w, the pisugar turns off. When I disconnect from Rpi USB port, the devices shuts down and I need to turn on pisegar with the button.

JdaieLin, 2020-04-07:
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

The reboot issue has nothing to do with the cable, it's due to the powerIC design. It will reboot the pi when switching from USB power to battery.

For the second point I guess you were connecting pi0w to an USB host (like a PC). The host will power the device which are connecting it. When there's external power source, pisugar might not able to detect power load and thus shutdown automatically. If you need to keep pi0w on when  disconnecting from the host, just turn the pisugar on before you unplug the USB.

Closed 2021-03-06.

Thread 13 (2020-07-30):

Strange colors when using with HyperPixel display

jzting, 2020-07-30:
I'm playing video with omxplayer on a 4" square HyperPixel display with a PiSugar2 and am seeing color issues similar to [this](https://github.com/pimoroni/fanshim-python/issues/70). Does the PiSugar interfere with the color data pins?

JdaieLin, 2020-07-30:
HyperPixel and PiSugar2 did use the same I2C pins. I2C bus is able to carry multiple devices.
Since it can still render correct image, the color issue is more likely caused by software.

jzting, 2020-07-30:
The color issue happens outside omxplayer (e.g. the colors are not showing correctly on the boot screen logo). When I remove the PiSugar, the colors return to normal.

Tobiah10, 2023-01-22:
TLDR: yes, the I2C pins that the PiSugar uses to communicate with the raspberry pi, are causing the color issues with the HyperPixel Display.

The HyperPixel Displays use every GPIO pin to transfer data to the display including the I2C pins that are used to communicate to the PiSugar battery pack, but they are not used like normal I2C pins. Those pins are used more like general data pins for the display and when the pi is trying to talk with the PiSugar, those signals are causing your issues with the display. I currently have a project using a PiSugar 3 pack and a HyperPixel4 display and haven't had any issues yet, but I also haven't set up the PiSugar software as the HyperPixel guide explicitly says to not use any of the GPIO pins or digital interfaces because all the pins are used. The HyperPixel 4  display does break out a few pins that can be changed to function as an I2C Interface, and the install guide does explain how to change the I2C interface in the firmware, but the pogo pins on the PiSugar do not connect to them. I'm going to attempt to run a few jumper wires from the I2C port on the HyperPixel display to the I2C pins on the PiSugar and see if doing that will allow me to set up and use the PiSugar software.

benlk, 2023-08-09:
@Tobiah10 Did you have any luck running jumper wires? What do your connections look like?

Tobiah10, 2023-08-09:
@benlk
Unfortunately, no. I tried a few different guides on setting up a secondary I2C bus on those pins but never got the PiSugar battery pack to communicate over it reliability. It worked now and again but, would randomly crash the webserver and freeze the entire pi sometimes. I eventually switched to an HDMI screen from waveshare and everything worked as intended. The main reason for my switch to a different screen was due to my project involving the use of a Camera Modual. When the OS sets up the resources for the camera modual, it reverts all I2C busses back to normal and locked them. The camera uses the I2C to send and receive some data. This threw everything I had done out the door. As far as wiring, I used the I2C breakout on the back of the HyperPixel display (my model came with a small plug installed, some don't apparently) and wired the corresponding SDA and SCL wires to the breakout pins on the back of the PiSugar battery pack. I did have to make a slight modification to the raspberry pi in order to get this to work and this may be where my Intermittent issues cane from. I had to break the normal I2C connection from the Raspberry pi to the PiSugar pack through the pogo-pins, otherwise there would be issues with signaling. I cut the pins as flush as I could to the board surface and coated them in nail polish to break that connection. That way I didn't destroy the pogo-pins on the PiSugar and it would work as intended if I ever reused it, and I could always remove the nail polish from the board with remover or heat if I needed that connection again.  I hope this helped and answered your question. I do belive it is possible to get working, I just wasn't completely successful.

Closed 2024-09-09.

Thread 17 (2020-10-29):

Interaction with other I2C devices

guillaumedavidphd, 2020-10-29:
Hi there,
I've noticed a consistent problem with PiSugar2 when used with other i2C devices. I'm currently trying to use a Pi Zero to log some environmental data and it has two I2C devices connected to it to that end. When I add the PiSugar2 and power the Pi with it the whole thing becomes unstable and the Pi completely loses power after a couple minutes. My devices are using I2C addresses that are different than the two I2C addresses used by the PiSugar2. I'd like to know if this is a known problem and if anyone else is experiencing this. I have 2 PiSugar2s connected to 2 different Pis and the same problem is occurring on both. This renders my PiSugar2s essentially useless for the original purpose I intended them for.

JdaieLin, 2020-11-11:
Hi, will the PiSuagr2 acts normally if you unload the extra I2C device?

guillaumedavidphd, 2020-11-11:
Both of my PiSugar2s work correctly without the I2C devices attached.

JdaieLin, 2020-11-22:
@wlmh110

wlmh110, 2020-11-23:
Hi,
Could you please provide what data is in I2C when all the devices work together?
And what devices do you use? If we can get one, it will more easily solve this problem.

guillaumedavidphd, 2020-11-24:
Could you specify what you mean by "provide what data is in I2C"? Here are the 2 I2C devices that I'm using in concurrence with PiSugar2:

- https://www.adafruit.com/product/4632
- https://www.adafruit.com/product/4636

Thanks for looking into it!

wlmh110, 2020-11-25:
Please use the i2c tool to read the address of 0x75 and 0x32.
i2cdump -y 1 0x32
i2cdump -y 1 0x75
Then you can see the data in these two addresses.

guillaumedavidphd, 2020-12-02:
It's a bit tricky. Since the PiSugar2 was not working, I removed it from my design and currently everything is packaged and in use. It would be a lot faster if you got your hands on the sensors I mentioned I tried it out for yourself.

tonyrog, 2020-12-10:
Here is an output where 0x32 is up and may be "talked" to, but 0x75 is gone.
Had this problem before but then 0x75 came back... (piSugar2)

i2cdetect -y 1
     0  1  2  3  4  5  6  7  8  9  a  b  c  d  e  f
00:          -- -- -- -- -- -- -- -- -- -- -- -- --
10: -- -- -- -- -- -- -- -- -- -- -- -- -- -- -- --
20: -- -- -- -- -- -- -- -- -- -- -- -- -- -- -- --
30: -- -- 32 -- -- -- -- -- -- -- -- -- -- -- -- --
40: -- -- -- -- -- -- -- -- -- -- -- -- -- -- -- --
50: -- -- -- -- -- -- -- -- -- -- -- -- -- -- -- --
60: -- -- -- -- -- -- -- -- -- -- -- -- -- -- -- --
70: -- -- -- -- -- -- -- --

tonyrog, 2020-12-10:
I turned piSuger2 off and pressed reset button for a while, then 0x75 came back.
Had not tried that sequence before...

i2cdetect -y 1
     0  1  2  3  4  5  6  7  8  9  a  b  c  d  e  f
00:          -- -- -- -- -- -- -- -- -- -- -- -- --
10: -- -- -- -- -- -- -- -- -- -- -- -- -- -- -- --
20: -- -- -- -- -- -- -- -- -- -- -- -- -- -- -- --
30: -- -- 32 -- -- -- -- -- -- -- -- -- -- -- -- --
40: -- -- -- -- -- -- -- -- -- -- -- -- -- -- -- --
50: -- -- -- -- -- -- -- -- -- -- -- -- -- -- -- --
60: -- -- -- -- -- -- -- -- -- -- -- -- -- -- -- --
70: -- -- -- -- -- 75 -- --

I turn piSugar2 on and then after a while it is gone again...

Repeated off - press reset - and it show up again, for a while then gone
even in off mode.

tonyrog, 2020-12-10:
If I repeat the procedure I can read voltage and initialize the ip5209 module (while in off mode) but after about 10-20 seconds it is gone again.  A press on reset will make it appear again and voltage may be read. But then ... all of this in off mode. Please? any way out of this?

wlmh110, 2020-12-13:
> If I repeat the procedure I can read voltage and initialize the ip5209 module (while in off mode) but after about 10-20 seconds it is gone again. A press on reset will make it appear again and voltage may be read. But then ... all of this in off mode. Please? any way out of this?

If 0x32 is working well, then the reason 0x75 doesn't show up because one other power supply is connected to the Raspberry Pi, please see issue #18

fabiantechera, 2021-06-25:
Hello! I have the same problem with PiSugar 2 Pro and a BME280 sensor. I do not get data from the BME sensor and also PiSugar doesn`t show information about charging and anything else.
Some help to get both works independently?
Thank you.

Some additional information:

It supposed that BME280 uses the 0x76 address

While Pisugar and BME280 are connected I get this from the console:

pi@raspberrypi:~ $ sudo i2cdump -y 1 0x32
No size specified (using byte-data access)
0 1 2 3 4 5 6 7 8 9 a b c d e f 0123456789abcdef
00: XX XX XX XX XX XX XX XX XX XX XX XX XX XX XX XX XXXXXXXXXXXXXXXX
10: XX XX XX XX XX XX ^C
pi@raspberrypi:~ $ sudo i2cdump -y 1 0x75
No size specified (using byte-data access)
0 1 2 3 4 5 6 7 8 9 a b c d e f 0123456789abcdef
00: XX XX XX XX XX XX XX XX XX XX XX XX XX XX XX ^C
pi@raspberrypi:~ $ sudo i2cdump -y 1 0x75
No size specified (using byte-data access)
0 1 2 3 4 5 6 7 8 9 a b c d e f 0123456789abcdef
00: XX XX XX XX XX XX XX XX XX XX XX XX XX XX XX XX XXXXXXXXXXXXXXXX
10: XX XX XX XX

pi@raspberrypi:~ $ sudo i2cdump -y 1 0x76
No size specified (using byte-data access)
0 1 2 3 4 5 6 7 8 9 a b c d e f 0123456789abcdef
00: XX XX XX XX XX XX XX XX XX XX XX XX XX XX XX XX XXXXXXXXXXXXXXXX

When BME280 not connected, only PiSugar Connected:

pi@raspberrypi:~ $ sudo i2cdump -y 1 0x32
No size specified (using byte-data access)
0 1 2 3 4 5 6 7 8 9 a b c d e f 0123456789abcdef
00: 12 01 a1 04 01 04 61 00 00 00 00 00 00 00 00 00 ??????a.........
10: 10 00 00 00 00 00 20 00 00 00 e0 0f 00 00 08 39 ?..... ...??..?9
20: 11 97 06 20 03 61 38 81 04 18 03 61 51 cf 79 fc ??? ?a8????aQ?y?
30: cd f2 0a b7 9f 71 df 22 b5 6a 02 35 bb 49 7d df ?????q?"?j?5?I}?
40: bd 7f bd b9 6d 35 5f 17 4f 56 6e 57 40 6f f3 f7 ????m5_?OVnW@o??
50: e6 d6 ff db c3 82 20 ce d5 54 ad 78 9a cf f3 c9 ??.??? ??T?x????
60: 6e cb 7b 76 fd f9 ec df 75 1d e1 9d 1c 7e 3e e6 n?{v????u????~>?
70: 76 3b 20 11 25 32 20 44 10 34 ff ff ff ff ff ff v; ?%2 D?4......
80: ff ff ff ff ff ff ff ff ff ff ff ff ff ff ff ff ................
90: ff ff ff ff ff ff ff ff ff ff ff ff ff ff ff ff ................
a0: ff ff ff ff ff ff ff ff ff ff ff ff ff ff ff ff ................
b0: ff ff ff ff ff ff ff ff ff ff ff ff ff ff ff ff ................
c0: ff ff ff ff ff ff ff ff ff ff ff ff ff ff ff ff ................
d0: ff ff ff ff ff ff ff ff ff ff ff ff ff ff ff ff ................
e0: ff ff ff ff ff ff ff ff ff ff ff ff ff ff ff ff ................
f0: ff ff ff ff ff ff ff ff ff ff ff ff ff ff ff ff ................

pi@raspberrypi:~ $ sudo i2cdump -y 1 0x75
No size specified (using byte-data access)
0 1 2 3 4 5 6 7 8 9 a b c d e f 0123456789abcdef
00: ea ff 77 26 bf 00 00 87 03 d0 25 00 fd 1e 04 03 ?.w&?..???%.????
10: 65 df 76 d5 0b 61 03 00 a0 be 00 b8 f8 20 00 00 e?v??a?.??.?? ..
20: ff 8a 92 08 d4 60 a6 63 4a b7 df 8f 28 00 00 00 .????`?cJ???(...
30: 3f 26 1a 70 d8 89 c3 c0 ba dc 11 40 d8 02 ad c0 ?&?p???????@????
40: 19 3d 11 57 55 be d4 e9 00 00 00 00 00 00 00 00 ?=?WU???........
50: 05 56 46 71 02 00 04 00 00 00 00 80 00 00 00 00 ?VFq?.?....?....
60: 00 00 00 00 00 00 00 00 00 00 00 00 00 00 00 00 ................
70: 37 ba 00 00 08 82 c0 58 00 00 00 26 03 13 08 48 7?..???X...&???H
80: 7f 8c a6 d0 5a 76 b6 87 b0 7f 8c a6 d0 5a 76 b6 ????Zv???????Zv?
90: 87 b0 53 66 86 af 56 86 be 5f 91 53 66 86 af 56 ??Sf??V???Sf??V
a0: 86 be 5f 91 b5 3a e9 7e 00 00 00 00 00 00 00 00 ????:?........
b0: f0 93 93 b3 51 7e 00 00 00 00 00 00 00 00 00 00 ????Q..........
c0: 8d 55 f7 fa 63 23 06 f6 eb fa 00 00 00 00 00 00 ?U??c#????......
d0: ba 0d cb 3e 9a 26 e2 01 00 00 00 00 c2 38 7a 0e ???>?&??....?8z?
e0: c0 00 00 81 1b 00 00 53 09 00 00 00 11 8d 10 00 ?..??..S?...???.
f0: 08 43 02 61 0a 00 00 70 01 0b 10 b9 00 00 00 00 ?C?a?..p????....

pi@raspberrypi:~ $ sudo i2cdump -y 1 0x76
No size specified (using byte-data access)
0 1 2 3 4 5 6 7 8 9 a b c d e f 0123456789abcdef
00: XX XX XX XX XX XX XX XX XX XX XX XX XX XX XX XX XXXXXXXXXXXXXXXX
10: XX XX XX XX XX XX XX XX XX XX XX XX XX XX XX XX XXXXXXXXXXXXXXXX
20: XX XX XX XX XX XX XX XX XX XX XX XX XX XX XX XX XXXXXXXXXXXXXXXX
30: XX XX XX XX XX XX XX XX XX XX XX XX XX XX XX XX XXXXXXXXXXXXXXXX
40: XX XX XX XX XX XX XX XX XX XX XX XX XX XX XX XX XXXXXXXXXXXXXXXX
50: XX XX XX XX XX XX XX XX XX XX XX XX XX XX XX XX XXXXXXXXXXXXXXXX
60: XX XX XX XX XX XX XX XX XX XX XX XX XX XX XX XX XXXXXXXXXXXXXXXX
70: XX XX XX XX XX XX XX XX XX XX XX XX XX XX XX XX XXXXXXXXXXXXXXXX
80: XX XX XX XX XX XX XX XX XX XX XX XX XX XX XX XX XXXXXXXXXXXXXXXX
90: XX XX XX XX XX XX XX XX XX XX XX XX XX XX XX XX XXXXXXXXXXXXXXXX
a0: XX XX XX XX XX XX XX XX XX XX XX XX XX XX XX XX XXXXXXXXXXXXXXXX
b0: XX XX XX XX XX XX XX XX XX XX XX XX XX XX XX XX XXXXXXXXXXXXXXXX
c0: XX XX XX XX XX XX XX XX XX XX XX XX XX XX XX XX XXXXXXXXXXXXXXXX
d0: XX XX XX XX XX XX XX XX XX XX XX XX XX XX XX XX XXXXXXXXXXXXXXXX
e0: XX XX XX XX XX XX XX XX XX XX XX XX XX XX XX XX XXXXXXXXXXXXXXXX
f0: XX XX XX XX XX XX XX XX XX XX XX XX XX XX XX XX XXXXXXXXXXXXXXXX

jan94, 2021-07-07:
I had the same issue and ended up creating a second i2c bus...

fabiantechera, 2021-07-07:
Hello jan94, thanks for your answer.
Yes, I did the same. Everything ok now.
Regards

tamugo, 2021-07-23:
Hello @fabiantechera I have the same issue with not being able to detect the PiSugar address when another device is connected. Can you tell me how you created the bus you used?

fabiantechera, 2021-07-26:
Hello @tamugo. I followed this guide.
https://www.instructables.com/Raspberry-PI-Multiple-I2c-Devices/

mlaity, 2021-11-10:
I am experiencing the same issue, using a Raspberry Pi 4B, OzzMaker BerryGPS-IMU-4, and PiSugar 2 Pro.  Were you ever able to resolve this other than creating a new i2c bus?  We can't just create additional I2C buses as both devices have built-in headers to connect to I2C Bus 1 on Pi Pins 3 and 5.

The I2C addresses continually come and go for each device, making both devices inaccessible.  There does not seem to be a conflict in I2C addresses between these devices, with the BerryGPS-IMU-v4 using 1c, 6a, and 77, and the PiSugar using 32 and 75.

fabiantechera, 2021-11-10:
Hello mlaity,
I know what you mean. Creating a new i2c bus works for me. I didn`t try any other solution because y made the connection with cables in different pins. Regards!

Closed 2024-09-01.

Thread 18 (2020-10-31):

ERROR pisugar_server] Invalid slave address: 117

sinoia, 2020-10-31:
● pisugar-server.service - pisugar-server
   Loaded: loaded (/lib/systemd/system/pisugar-server.service; enabled; vendor preset: enabled)
   Active: active (running) since Sat 2020-10-31 07:42:07 GMT; 19min ago
 Main PID: 267 (pisugar-server)
   Memory: 4.7M
   CGroup: /system.slice/pisugar-server.service
           └─267 /usr/bin/pisugar-server --config config.json --model PiSugar 2 (2-LEDs) --web /usr/share/pisugar-server/web --ht

Oct 31 08:01:27 raspberrypi pisugar-server[267]: [2020-10-31T08:01:27Z ERROR pisugar_server] Invalid slave address: 117
Oct 31 08:01:27 raspberrypi pisugar-server[267]: [2020-10-31T08:01:27Z ERROR pisugar_server] Invalid slave address: 117
Oct 31 08:01:28 raspberrypi pisugar-server[267]: [2020-10-31T08:01:28Z ERROR pisugar_server] Invalid slave address: 117
Oct 31 08:01:28 raspberrypi pisugar-server[267]: [2020-10-31T08:01:28Z ERROR pisugar_server] Invalid slave address: 117
Oct 31 08:01:28 raspberrypi pisugar-server[267]: [2020-10-31T08:01:28Z ERROR pisugar_server] Invalid slave address: 117
Oct 31 08:01:29 raspberrypi pisugar-server[267]: [2020-10-31T08:01:29Z ERROR pisugar_server] Invalid slave address: 117
Oct 31 08:01:29 raspberrypi pisugar-server[267]: [2020-10-31T08:01:29Z ERROR pisugar_server] Invalid slave address: 117
Oct 31 08:01:30 raspberrypi pisugar-server[267]: [2020-10-31T08:01:30Z ERROR pisugar_server] Invalid slave address: 117
Oct 31 08:01:30 raspberrypi pisugar-server[267]: [2020-10-31T08:01:30Z ERROR pisugar_server] Invalid slave address: 117
Oct 31 08:01:30 raspberrypi pisugar-server[267]: [2020-10-31T08:01:30Z ERROR pisugar_server] Invalid slave address: 117

JdaieLin, 2020-11-11:
@fengyc

fengyc, 2020-11-12:
@sinoia Whether the i2c function is enabled or not? See https://github.com/PiSugar/pisugar-power-manager-rs#prerequisites

timgunter, 2020-11-23:
I am also having this issue with a new pisugar2 2-led model. Pisugar-server is able to connect occasionally, but most of the time it cannot and the "invalid slave address: 117" error shows up in the system log. I have another I2C device at address 0x1a that is working.

tonyrog, 2020-12-10:
I have the same problem on 2 devices the 117 (0x75) slave does not show up.
RTC 50 (0x32) do show up. They started behaving strange after a while. Any workarounds? I have 2 more that are not in use yet!

wlmh110, 2020-12-13:
> I have the same problem on 2 devices the 117 (0x75) slave does not show up.
> RTC 50 (0x32) do show up. They started behaving strange after a while. Any workarounds? I have 2 more that are not in use yet!

The reason 0x75 doesn't show up because one other power supply is connected to the Raspberry Pi.
If you use PiSuga2 on Pwnagotchi, we suggest you use this image, we have installed PiSugar Plugin that can show the battery level on the E-ink screen:
https://mega.nz/file/emwmjZhZ#GKE_yJ9i14KB6S9o3kcSokmQy-FacAaNd2b2GQd-EZY

wlmh110, 2020-12-13:
> I am also having this issue with a new pisugar2 2-led model. Pisugar-server is able to connect occasionally, but most of the time it cannot and the "invalid slave address: 117" error shows up in the system log. I have another I2C device at address 0x1a that is working.

If 0x32 is working well, then the reason 0x75 doesn't show up because one other power supply is connected to the Raspberry Pi.

tonyrog, 2020-12-13:
Why would that be a problem? And how can that explain the things we are seeing? Is it a bug or is it designed that way? If it is a bug, can we mod the product some how to make it accept another USB cable? In that application me and my colleague is working on we are using the gadget port with USB g_ether. Why does the i2c devices show up for 10-20 seconds when I push the tap button? I am not even using the button for anything.

3dlabsio, 2020-12-27:
Also experiencing this issue on a Compute Module 4 with CM4 IO Board. Is there a way to change the occupied i2c address? We are integrating the pisugar into a project and if this doesn't work we'll have to return all the units we purchased.

wlmh110, 2021-01-02:
> Why would that be a problem? And how can that explain the things we are seeing? Is it a bug or is it designed that way? If it is a bug, can we mod the product some how to make it accept another USB cable? In that application me and my colleague is working on we are using the gadget port with USB g_ether. Why does the i2c devices show up for 10-20 seconds when I push the tap button? I am not even using the button for anything.

Hi, It designed like this. When an extra power source is connected, Pi will get power from the extra power source, then PiSugar has nothing to do, so it will shut down automatically.
We add an option in the 1.4.8 version, it will close the automatic shutdown function, so even there is an extra power source, PiSugar won't shutdown.
But be careful, while this option is chosen, Pisugar can only be shut down with the system when using the shutdown command or the battery is run out. Even turn the switch off, the power IC will still work.

wlmh110, 2021-01-02:
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

We don't quite understand what problem you have met. It seems that both addresses are working well.
We can't change the I2C address of PiSugar, may think about this in the next generation.

tonyrog, 2021-01-02:
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

Ok. Thank you for the reply. I think I may need to use that option since we use a gadget ether to communicate sometimes. I will report back on the progress on this.

matthiasg, 2021-12-30:
What about address 50 ? What is that used for ?

fengyc, 2021-12-31:
> What about address 50 ? What is that used for ?

0x32 is the i2c address of rtc chip in pisugar2.

matthiasg, 2021-12-31:
That explains why I had rtc issues. Updated to 1.6.x and the problem vanished. Wasn't the soldering though but an issue with raspberry zero 2 compatibility

xlla, 2022-09-29:
> If you use PiSuga2 on Pwnagotchi, we suggest you use this image, we have installed PiSugar Plugin that can show the battery level on the E-ink screen:

hi @wlmh110 ,  how to show the battery level on the E-ink screen using my pwnagotchi build?

wlmh110, 2022-09-30:
> > If you use PiSuga2 on Pwnagotchi, we suggest you use this image, we have installed PiSugar Plugin that can show the battery level on the E-ink screen:
>
> hi @wlmh110 , how to show the battery level on the E-ink screen using my pwnagotchi build?

Hi, please use this image, which we have installed all part already:
https://mega.nz/file/8XcUQZhD#TngZV9OZaPXLWnqIwmvzJeYdL0ddT33S21EQAiARcwc

Closed 2024-08-31.

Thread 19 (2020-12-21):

Is there a reason I get low power output sometimes?

justanothermatt, 2020-12-21:
I'm using the PiSugar2 with a Raspberry Pi Zero and a a PiOLED. Sometimes when I use the battery the PiOLED only gets ~1.3V on pins 3 and 5. Because of this, my screen won't turn on. Is there any reason this would be happening?

JdaieLin, 2021-01-02:
@wlmh110

wlmh110, 2021-01-02:
> I'm using the PiSugar2 with a Raspberry Pi Zero and a a PiOLED. Sometimes when I use the battery the PiOLED only gets ~1.3V on pins 3 and 5. Because of this, my screen won't turn on. Is there any reason this would be happening?

Hi, we haven't seen this yet.
Could you describe under what circumstances this happened?

justanothermatt, 2021-01-04:
PiSugar 2 is connected to a Pi Zero W. Which has [this ](https://www.adafruit.com/product/3527) PiOLED on top of it. When I plug the Pi Zero into external power the screen works fine. When I use the battery sometimes it will work and other times it wont. The voltage on pins 3 and 5 are too low and `sudo i2cdetect -y 1` shows weird values typically looking something like this:

```
     0  1  2  3  4  5  6  7  8  9  a  b  c  d  e  f
00:          03 04 -  -   -   - 09 0a 0b 0c 0d -  -
10: -  -  - 13 14 15 16 - -  -  -  1b 1c 1d 1e -
20: - - - 23 24 25 26 27 - - -  - 2c 2d 2e 2f
30: 30 - -  -  - 35 36 37 - -  -  -  3c 3d 3e 3f
40: 40 - -  - - 45 46 47 48 49 - - - - 4e 4f
50: 50 51 - - -  -  -  57 58 - - -  -  -   - 5e 5f
60: 60 - - -  -  -  66 67 68 69 -  - -  - 6e 6f
70: 70 71 72 73 - - - -
```

Note that it doesn't ALWAYS look like this. Sometimes the occupied addresses are different. It seems to me like there's an issue during initial boot of the PiSugar. How does it interact with the i2c bus on boot? It seems like it's initializing every address but getting interrupted at some point and this issue is happening

wlmh110, 2021-01-05:
Hi,
It seems that PiSugar can’t work with PiOLED.
This is because Raspberry Pi use an nonstandard design on I2C, it pull down
the voltage instead of pull up.
PiSugar only can pull up the voltage of I2C a little.
So it can work with most of devices, but due to the IC design, when it been
pull down too low on the boot time, I2C interface will turn into LED
interface, it cause the mess.
We will fix this problem in the next version of PiSugar, but we can’t do
anything about it on PiSugar 2/PiSugar 2 Pro.
We are very sorry about that.
PiSugar Team

Matt Walker <notifications@github.com>于2021年1月4日 周一22:15写道：

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

justanothermatt, 2021-01-05:
Ah I understand. I've seen photos of screen working with the PiSugar, would any of those be able to work with PiSugar 2? If so, could you link to those screens?

justanothermatt, 2021-01-07:
Been doing research on this topic the past couple of days and I can't find any documentation that says the Raspberry Pi pulls down I2C. In fact everything I see says they have [two pull up resistors on I2C](https://forums.adafruit.com/viewtopic.php?f=8&p=639992#:~:text=The%20RasPi%20and%20Arduino%20both,value%20(20k%20to%2040k).) Any ideas with that?

wlmh110, 2021-01-07:
Hi，
It's two different things.
We need to pull up the voltage before the system power-up, in another word,
there should be a large resistance between I2C interface and the GND.

You can test the voltage between the I2C interface and the GND while the
system is off.
If PiSugar connects nothing, normally it will be 3V.

We have used some screens that don't use the I2C interface, and they work
well. But as we know, for now, all adafruit screens do not work well with
PiSugar2.
Hope that helps
PiSugar Team

Matt Walker <notifications@github.com> 于2021年1月7日周四 下午9:04写道：

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

justanothermatt, 2021-01-07:
Do you have links to the SPI screen you have used?

wlmh110, 2021-01-10:
Hi,
Yes, we have tested some SPI screens, but we can't find the same name on
Amazon.
We tried to send you the picture, but the mail has been denied by the
server.
Here is the link to Taobao
https://item.taobao.com/item.htm?spm=a1z09.2.0.0.69382e8d2GvgHO&id=615754762052&_u=ahqg6qa8241
Hope that helps
PiSugar Team

Matt Walker <notifications@github.com> 于2021年1月7日周四 下午11:28写道：

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

Closed 2021-01-11.

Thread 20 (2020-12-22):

Server doesn't seem to shut down the pi based on PiSugar2's battery or button?

mildmojo, 2020-12-22:
I just got a PiSugar2. I think it's the 4-LED version, though I only count 3 (blue charging, green full charge, blue power on). I used the installer script from the wiki to install the server software into a DIetPi installation from videolooper.de (image v2.3), running on an old Pi Zero v1.2. The server is running, I can visit the very pretty control page which displays the battery status, RTC info, and lets me change settings.

When I use the web UI to configure the PiSugar button to shut the pi down on a long press, it doesn't seem to have any effect. I can hold the button for 10 seconds or more and nothing happens. Same for short or double-press settings. I can see the output changing in `sudo i2cdetect -y 1 0x32` when I press the button. A bunch of 'X' characters appear on the ASCII output side.

To test the low-battery shutdown, I used the web UI to set it to shut down immediately at 3% battery, then edited `/etc/pisugar-server/config.json` and set "auto_shutdown_level" to "95.0" for testing. I restarted the server with `sudo systemctl restart pisugar-server`, visited the control page, and left it open until the battery percentage hit 95%. Nothing appeared in `dmesg` logs, and the pi did not shut down.

I also have an Adafruit 2.8" resistive-touch PiTFT LCD attached.

Any advice? Thanks!

_(Also: It's not clear to me if the UI is configuring the PiSugar firmware settings, the server settings, or both. It's also not clear to me what functions the server is responsible for, and what the PiSugar is responsible for. When setting the low-battery shutdown, does the server watch for that? Or does the PiSugar watch, and use I2C to signal the server to shut the system down? When configuring the delay for low-battery shutdown, is that a delay between the low battery condition and the `sudo shutdown now`, or a delay between the shutdown command and the PiSugar firmware poweroff? Do I have to configure anything manually to make the PiSugar allow the system to shut down before powering off, or is that how the system already behaves?)_

JdaieLin, 2021-01-02:
It should be 2-LED version. 4-led refers to 4 leds indicating power level, not all leds in total.

mildmojo, 2021-02-20:
Ah, thanks! I think this fixed the shutdown issues.

Closed 2021-02-20.

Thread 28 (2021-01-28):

BerryGPS-IMU compatibility

mhgwilliams, 2021-01-28:
Hello,

I'm using the pisugar 2 with the raspberry pi zero w. I love the battery, super easy to get started and the form factor is really nice to use. However, I'm noticing some issue with my i2c devices when I use the battery. For whatever reason, when running 'i2cdetect -y 1' after installing both the pisugar 2 and the berrygps-imu hat, I get intermittent listing of devices. If I run that command over and over, sometimes I'll get correct listings, and other times the address where the device was is listed as empty. I checked my wiring and it doesn't seem to be the issue. when running via usb I don't get this issue. I double checked the addresses on the i2c bus aren't overlapping, so that doesn't seem to be the problem either.

[BerryGPS-IMU for reference.](https://ozzmaker.com/product/berrygps-imu/)

Am I missing something simple? not sure where this instability is coming from, would love a suggestion on how to troubleshoot if anyone else has similar issues.

mhgwilliams, 2021-01-28:
Saw in issue #17 you requested specific addresses info dumped, so here's that preemptively.

pi@pizero:~ $ i2cdump -y 1 0x32
> No size specified (using byte-data access)
     0  1  2  3  4  5  6  7  8  9  a  b  c  d  e  f    0123456789abcdef
00: XX XX XX XX XX XX XX XX XX XX XX XX XX XX XX XX    XXXXXXXXXXXXXXXX
10: XX XX XX XX XX XX XX XX XX XX XX XX XX XX XX XX    XXXXXXXXXXXXXXXX
etc, etc...

pi@pizero:~ $ i2cdump -y 1 0x75

> No size specified (using byte-data access)
     0  1  2  3  4  5  6  7  8  9  a  b  c  d  e  f    0123456789abcdef
00: XX XX XX XX XX XX XX XX XX XX XX XX XX XX XX XX    XXXXXXXXXXXXXXXX
10: XX XX XX XX XX XX XX XX XX XX XX XX XX XX XX XX    XXXXXXXXXXXXXXXX
etc, etc...

Here is what I get with all devices connected using i2cdetect.

pi@pizero:~ $ i2cdetect -y 1

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
40: -- -- -- -- -- -- -- -- -- -- -- -- -- -- -- --
50: -- -- -- -- -- -- -- -- -- -- -- -- -- -- -- --
60: -- -- -- -- -- -- -- -- -- -- 6a -- -- -- -- --
70: -- -- -- -- -- -- -- 77

JdaieLin, 2021-03-06:
@wlmh110

jan94, 2021-04-08:
I have the same issue.
Is there anything we can do to counteract that problem ?

jan94, 2021-05-03:
Any progress so far ?

fabiantechera, 2021-06-25:
Hello! I have the same problem with PiSugar 2 Pro and a BME280 sensor. I do not get data from the BME sensor and also PiSugar doesn`t show information about charging and anything else.
Some help to get both working independently?
Thank you.

Some additional information:

It supposed that BME use the 0x76 address

While Pisugar and BME280 is connected I get this from the console:

pi@raspberrypi:~ $ sudo i2cdump -y 1 0x32
No size specified (using byte-data access)
     0  1  2  3  4  5  6  7  8  9  a  b  c  d  e  f    0123456789abcdef
00: XX XX XX XX XX XX XX XX XX XX XX XX XX XX XX XX    XXXXXXXXXXXXXXXX
10: XX XX XX XX XX XX ^C
pi@raspberrypi:~ $ sudo i2cdump -y 1 0x75
No size specified (using byte-data access)
     0  1  2  3  4  5  6  7  8  9  a  b  c  d  e  f    0123456789abcdef
00: XX XX XX XX XX XX XX XX XX XX XX XX XX XX XX ^C
pi@raspberrypi:~ $ sudo i2cdump -y 1 0x75
No size specified (using byte-data access)
     0  1  2  3  4  5  6  7  8  9  a  b  c  d  e  f    0123456789abcdef
00: XX XX XX XX XX XX XX XX XX XX XX XX XX XX XX XX    XXXXXXXXXXXXXXXX
10: XX XX XX XX

pi@raspberrypi:~ $ sudo i2cdump -y 1 0x76
No size specified (using byte-data access)
     0  1  2  3  4  5  6  7  8  9  a  b  c  d  e  f    0123456789abcdef
00: XX XX XX XX XX XX XX XX XX XX XX XX XX XX XX XX    XXXXXXXXXXXXXXXX

When BME280 not connected, only PiSugar Connected:

pi@raspberrypi:~ $ sudo i2cdump -y 1 0x32
No size specified (using byte-data access)
     0  1  2  3  4  5  6  7  8  9  a  b  c  d  e  f    0123456789abcdef
00: 12 01 a1 04 01 04 61 00 00 00 00 00 00 00 00 00    ??????a.........
10: 10 00 00 00 00 00 20 00 00 00 e0 0f 00 00 08 39    ?..... ...??..?9
20: 11 97 06 20 03 61 38 81 04 18 03 61 51 cf 79 fc    ??? ?a8????aQ?y?
30: cd f2 0a b7 9f 71 df 22 b5 6a 02 35 bb 49 7d df    ?????q?"?j?5?I}?
40: bd 7f bd b9 6d 35 5f 17 4f 56 6e 57 40 6f f3 f7    ????m5_?OVnW@o??
50: e6 d6 ff db c3 82 20 ce d5 54 ad 78 9a cf f3 c9    ??.??? ??T?x????
60: 6e cb 7b 76 fd f9 ec df 75 1d e1 9d 1c 7e 3e e6    n?{v????u????~>?
70: 76 3b 20 11 25 32 20 44 10 34 ff ff ff ff ff ff    v; ?%2 D?4......
80: ff ff ff ff ff ff ff ff ff ff ff ff ff ff ff ff    ................
90: ff ff ff ff ff ff ff ff ff ff ff ff ff ff ff ff    ................
a0: ff ff ff ff ff ff ff ff ff ff ff ff ff ff ff ff    ................
b0: ff ff ff ff ff ff ff ff ff ff ff ff ff ff ff ff    ................
c0: ff ff ff ff ff ff ff ff ff ff ff ff ff ff ff ff    ................
d0: ff ff ff ff ff ff ff ff ff ff ff ff ff ff ff ff    ................
e0: ff ff ff ff ff ff ff ff ff ff ff ff ff ff ff ff    ................
f0: ff ff ff ff ff ff ff ff ff ff ff ff ff ff ff ff    ................

pi@raspberrypi:~ $ sudo i2cdump -y 1 0x75
No size specified (using byte-data access)
     0  1  2  3  4  5  6  7  8  9  a  b  c  d  e  f    0123456789abcdef
00: ea ff 77 26 bf 00 00 87 03 d0 25 00 fd 1e 04 03    ?.w&?..???%.????
10: 65 df 76 d5 0b 61 03 00 a0 be 00 b8 f8 20 00 00    e?v??a?.??.?? ..
20: ff 8a 92 08 d4 60 a6 63 4a b7 df 8f 28 00 00 00    .????`?cJ???(...
30: 3f 26 1a 70 d8 89 c3 c0 ba dc 11 40 d8 02 ad c0    ?&?p???????@????
40: 19 3d 11 57 55 be d4 e9 00 00 00 00 00 00 00 00    ?=?WU???........
50: 05 56 46 71 02 00 04 00 00 00 00 80 00 00 00 00    ?VFq?.?....?....
60: 00 00 00 00 00 00 00 00 00 00 00 00 00 00 00 00    ................
70: 37 ba 00 00 08 82 c0 58 00 00 00 26 03 13 08 48    7?..???X...&???H
80: 7f 8c a6 d0 5a 76 b6 87 b0 7f 8c a6 d0 5a 76 b6    ????Zv???????Zv?
90: 87 b0 53 66 86 af 56 86 be 5f 91 53 66 86 af 56    ??Sf??V??_?Sf??V
a0: 86 be 5f 91 b5 3a e9 7e 00 00 00 00 00 00 00 00    ??_??:?~........
b0: f0 93 93 b3 51 7e 00 00 00 00 00 00 00 00 00 00    ????Q~..........
c0: 8d 55 f7 fa 63 23 06 f6 eb fa 00 00 00 00 00 00    ?U??c#????......
d0: ba 0d cb 3e 9a 26 e2 01 00 00 00 00 c2 38 7a 0e    ???>?&??....?8z?
e0: c0 00 00 81 1b 00 00 53 09 00 00 00 11 8d 10 00    ?..??..S?...???.
f0: 08 43 02 61 0a 00 00 70 01 0b 10 b9 00 00 00 00    ?C?a?..p????....

pi@raspberrypi:~ $ sudo i2cdump -y 1 0x76
No size specified (using byte-data access)
     0  1  2  3  4  5  6  7  8  9  a  b  c  d  e  f    0123456789abcdef
00: XX XX XX XX XX XX XX XX XX XX XX XX XX XX XX XX    XXXXXXXXXXXXXXXX
10: XX XX XX XX XX XX XX XX XX XX XX XX XX XX XX XX    XXXXXXXXXXXXXXXX
20: XX XX XX XX XX XX XX XX XX XX XX XX XX XX XX XX    XXXXXXXXXXXXXXXX
30: XX XX XX XX XX XX XX XX XX XX XX XX XX XX XX XX    XXXXXXXXXXXXXXXX
40: XX XX XX XX XX XX XX XX XX XX XX XX XX XX XX XX    XXXXXXXXXXXXXXXX
50: XX XX XX XX XX XX XX XX XX XX XX XX XX XX XX XX    XXXXXXXXXXXXXXXX
60: XX XX XX XX XX XX XX XX XX XX XX XX XX XX XX XX    XXXXXXXXXXXXXXXX
70: XX XX XX XX XX XX XX XX XX XX XX XX XX XX XX XX    XXXXXXXXXXXXXXXX
80: XX XX XX XX XX XX XX XX XX XX XX XX XX XX XX XX    XXXXXXXXXXXXXXXX
90: XX XX XX XX XX XX XX XX XX XX XX XX XX XX XX XX    XXXXXXXXXXXXXXXX
a0: XX XX XX XX XX XX XX XX XX XX XX XX XX XX XX XX    XXXXXXXXXXXXXXXX
b0: XX XX XX XX XX XX XX XX XX XX XX XX XX XX XX XX    XXXXXXXXXXXXXXXX
c0: XX XX XX XX XX XX XX XX XX XX XX XX XX XX XX XX    XXXXXXXXXXXXXXXX
d0: XX XX XX XX XX XX XX XX XX XX XX XX XX XX XX XX    XXXXXXXXXXXXXXXX
e0: XX XX XX XX XX XX XX XX XX XX XX XX XX XX XX XX    XXXXXXXXXXXXXXXX
f0: XX XX XX XX XX XX XX XX XX XX XX XX XX XX XX XX    XXXXXXXXXXXXXXXX

Closed 2024-08-25.

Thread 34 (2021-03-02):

PiSugar 2 Pro will not turn on

stphnduvall, 2021-03-02:
When I got the PS2Pro a few weeks ago I had an issue when turning the board on. No LED's would turn on and it would not give power to the raspberry pi. I broke out my multimeter and check that the battery had enough voltage and it did. After trying many different things it all of a sudden it just started working. I don't know what I did

Today I unplugged the battery and after plugging it back in I am having the same issue. I have it plugged in and charging right now but before I unplugged it it was around 60%, I feel like that should not be the problem.

Any suggestions or help would be appreciated. Thanks.

stphnduvall, 2021-03-02:
Found that there is an "Activate" button which I had believed I already pressed. I'm not really sure why there is an on/off switch and a button as well. Its not very well documented either. In the readme its written under the "Features" section as "On-board Switch" but on the board its labeled "Activate."

Tetsujinfr, 2022-03-14:
Oh boy, @stphnduvall you are my hero of the day. I was running nuts not finding the issue with my pisugar. Then thanks to your post I rediscovered that activate button, and immediately the i2c 75 adress of the pisugar appeared again and it worked back fine.

In case it helps anyone else, in my scenario I left my rpi and pisugar turned on during the night, and not sure why but next morning all was off.
Not sure what happen, maybe my regular charger was switch off and my pisugar got drained.
Anyhow, it would not turn back on using the power on button no matter what, until I press the activate button.
So if your system is in a case all wrapped up carefully in a case and you have this issue, I sympathise.

Closed 2021-03-02.

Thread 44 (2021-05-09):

Bad tolerances on case

hijackeel, 2021-05-09:
1. When I tried to use the power switch, the sliding tab snapped off the actual component. Now I need to desolder and replace it. The hole for the switch is too wide and doesn't stop the user from sliding the switch too far, which is easy to do since additionally the fit on the power switch's plastic cover is way too tight, requiring force. Also, when the switch is slid all the way in either direction, an ugly gap is visible.

2. It's difficult to place the pi and pisugar boards correctly inside the shell because they are held too tightly, as if designed for friction fit, which is unnecessary since they are screwed in place afterwards. I had to flex the case and push quite hard on the boards to get them in. Fixing this might help partially alleviate problem 1 above.

3. There is a slot (with a bar blocking it that needs to be cut out with an x-acto knife) for the SD card, but it can't actually be used because the shell and the pi board are too far apart on that side.

4. The epaper cap bulges as if it's about to pop off. The shell might need to be a mm or two taller.

5. The reset button is loose and rattles.

6. The holes for the various ports don't line up perfectly.

hijackeel, 2021-05-09:
Issue #42 ("Fragile clips on caps") could also be considered a tolerance problem.

Closed 2024-08-11.

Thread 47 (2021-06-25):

External switches.

bongoplayingmonkey, 2021-06-25:
I need to install the pisugar 2 pro into a case where the power switch isn't accessible. Any tips for adding in an external switch to solve that issue?

bongoplayingmonkey, 2021-06-27:
Can there at least be some JST sockets to extend the switches out to surface mounts on future versions?

JdaieLin, 2021-07-18:
@wlmh110

GSVNoFixedabode, 2021-08-11:
Any update on this?  I have the same requirement.

wlmh110, 2021-08-16:
Here is the PCB of the PiSugar 2 Pro power switch.
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
When the 2(VOUTC1) pin is connected with 3(VOUT1), PiSugar will work, and when the 2(VOUTC1) pin is connected with 1(GND), it will shut down.

fheslouin, 2021-08-31:
@wlmh110 where can we find those pins ? PCB is not showing any of these names

sledgehammer617, 2022-03-01:
Any updates on this? Anyone figure out how to do it?

I was also hoping to install my pisugar 2 pro in a case with an external button.

Acluff1, 2022-03-15:
I figured it out! Simply solder your toggle switch wires to "Ctrl" and "Off," leave the main switch in the "On" position and bam!
![Uploading 20220314_203003.jpg…]()

sledgehammer617, 2022-03-16:
@Acluff1 Cool, thanks!

sjin4903, 2022-07-19:
@HaochengZheng
I want to know exactly where you're connecting.

HaochengZheng, 2022-07-19:
After you remove the metal cap over the switch and the plastic handle, there are 3 metal areas underneath. Originally, when the switch is at "off", middle and left metal areas are connected; when the switch is at "on", middle and right part is connected. So get a slide switch, solder 3 pins of slide switch to each metal area(right pin- right, middle-middle, left-left)

HaochengZheng, 2022-07-19:
@sjin4903
After you remove the metal cap over the switch and the plastic handle, there are 3 metal areas underneath. Originally, when the switch is at "off", middle and left metal areas are connected; when the switch is at "on", middle and right part is connected. So get a slide switch, solder 3 pins of slide switch to each metal area(right pin- right, middle-middle, left-left)

sjin4903, 2022-07-19:
@HaochengZheng
Problem solved! Thanks

stokes776, 2022-07-29:
Any idea if I want to just connect a switch that has two leads, not three?

OFF = Middle and LEFT so...... X X o
ON = Middle and Right          o X X

Feels like maybe I could just ignore that orange wire you have in your photo?

HaochengZheng, 2022-07-29:
@stokes776 I don't think so. I guess there is some kind of capacitor, so you have to make MIDDLE and LEFT pad connected before switching to MIDDLE and RIGHT

spaceman1988, 2023-04-29:
> I figured it out! Simply solder your toggle switch wires to "Ctrl" and "Off," leave the main switch in the "On" position and bam! I should add this was a pisugar S plus.
>
> 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

I have an "S". The document isn't very clear on what the CTRL-OFF-ON pinouts actually do. Do the pinouts control power going to the Pi (turning power on and off), or do the pins set the state of the Pi's GPIO3?

I have a Pi Screen installed and can safely shutdown the Pi from the screen, but since it's in a case I need a way to turn in back on. Referring to your photo, I'm assuming these pins are controlling power to the Pi your toggle switch in one direction would take power away from the Pi and flipping it the other way would turn it back on. Correct? If all I wanted to do was turn it back on from screen-triggered shutdown then a momentary pushbutton between CTRL and OFF should do the trick.

Closed 2024-08-08.

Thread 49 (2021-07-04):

Procedure for shutting down and starting up

OctaneInteractive, 2021-07-04:
Hi!

I have a PiSugar 2 Pro, and I'm a bit confused about the correct procedure for shutting down and starting up again.

The first time I used it, I pressed the "Activate" button for 2 seconds, then flicked the switch.

When shutting it down, I shut down the OS, then flick the switch.

When starting up again, do I have to press the "Activate" button for 2 seconds before flicking the switch?

I think there should be a table explaining the different button and switch combinations and under what conditions.

JdaieLin, 2021-07-18:
Hi, normally there is not need to press active button unless the battery was run out. Activation is some kind of protective schema of the Injoinic chip, and it's also not well documented in the chip datasheet. So we decide to use a replace the chip, avoid Injoinic. If you still need need to activate every time before boot, please contact pisugar.zero@gmail.com for replacement. Thanks!

psi5asp, 2021-08-12:
No need to touch the PiSugar when shutting down the RPi (unless as stated above, if the battery runs dry).

The PiSugar will keep its lights on when the RPi lights are off (RPi = shutdown).

Kung-Foo-Kamel, 2021-08-23:
To power you Pi back on after it has been Halted or safely powered down, just momentary short Pin 5 to Pin 6 on the GPIO header, this will power the Pi back on.

You can make a small button and fix it to you case for easy access.

fheslouin, 2021-08-31:
Shorting Pin 5 & 6, has no effect. Did you manage to have it working ?

Kung-Foo-Kamel, 2021-09-02:
Yes it works perfectly for me, I send the halt or poweroff command through SSH, and I have a momentary press button connected to pins 5 and 6, one press and the Pi fires back up.

The Pi must already be up and running via the initial start-up procedure for the PISUGER2 Pro, but after that it will power up perfectly for me.

Below is an image of my custom Pi Cluster and one operational module with the start-up button installed.

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

fheslouin, 2021-09-13:
Yes, you are right, I had probably mess something ! Thanks

funkyfourier, 2022-05-03:
I have not been able to power up the Pi shorting pins 5 and 6 when connected to the Pi Sugar 2 Pro. When powered from the wall socket USB plug I notice that after shutting down the red power indicator light on the Pi stays lit, and in that situation shorting pins 5 and 6 powers it on. However, when powered from the Pi Sugar, the red power indicator light turns completely off after (safely) shutting down the Pi.

Should there not be some power coming from the Pi Sugar at all times? Or is it supposed to cut completely off like this?

NexGen-3D-Printing, 2022-05-03:
Mine does the same, if you pull power from the Pi Sugar and shutdown the RPI, you will need to power everything backup from the button on the Pi Sugar.

Seems like an obvious design flaw, they should have just provided some pins for a simple momentary button input that could both power up and power down the RPI through the Pi Sugar, regardless of the external power input status (provided there is sufficient battery charge).

This is an example of another great product idea, that is "almost" there, they got to about 80% and launched it, good idea, good product, but missing a couple of important key features still.

On a side note, keep your eye on the battery pack, I purchased 6 of these, setup 5 of them, 3 out of the five resulted in swollen battery packs that started to warp the PLA enclosures I made, and I had to discard them as they were on the verge of bursting/combusting, extremely bad for a device that could be locked away as an IOT like product, I will be swapping all the packs out for some good quality Samsung/Panasonic 18650's, not a fan of these pouch cells.

Closed 2024-08-06.

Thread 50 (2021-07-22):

Issue with other I2C devices

tamugo, 2021-07-22:
I am working with two Qwiic sensors connected to a raspberry pi zero via a qwiic pHAT. When the pHAT is not connected the I2C addresses of the PiSugar2 can be detected and data can be read from it. However, when I connect the pHAT, the addresses of the PiSugar are no longer detected but the addresses of the two sensors are. Any help in solving this would be really appreciated.

JdaieLin, 2021-07-29:
@wlmh110

ahmed-mans, 2021-08-08:
I had a similar problem where I had an infrared camera working on I2C and my PiSugar2 Pro with a Rpi 4B. I could not use both devices when they were connected to the Rpi. Normally they should have cause their I2C adresses were different but somehow there was a problem. What I did to solve it was to just choose another I2C bus for my infrared camera and changed the software accordingly and it worked.

Hope it can help you ;)

chickenherb, 2021-09-09:
I have similar problems with my PiSugar2 and I2C comunications.

When I use my raspberry pi zero w with PiSugar2 only it works fine:
pi@zeropi:~ $ sudo i2cdetect -y 1
     0  1  2  3  4  5  6  7  8  9  a  b  c  d  e  f
00:          -- -- -- -- -- -- -- -- -- -- -- -- --
10: -- -- -- -- -- -- -- -- -- -- -- -- -- -- -- --
20: -- -- -- -- -- -- -- -- -- -- -- -- -- -- -- --
30: -- -- 32 -- -- -- -- -- -- -- -- -- -- -- -- --
40: -- -- -- -- -- -- -- -- -- -- -- -- -- -- -- --
50: -- -- -- -- -- -- -- -- -- -- -- -- -- -- -- --
60: -- -- -- -- -- -- -- -- -- -- -- -- -- -- -- --
70: -- -- -- -- -- 75 -- --

When I use my Waveshare 4-Channel INA219 HAT without PiSugar on my raspery pi zero w, it works fine too:
pi@zeropi:~ $ sudo i2cdetect -y 1
     0  1  2  3  4  5  6  7  8  9  a  b  c  d  e  f
00:          -- -- -- -- -- -- -- -- -- -- -- -- --
10: -- -- -- -- -- -- -- -- -- -- -- -- -- -- -- --
20: -- -- -- -- -- -- -- -- -- -- -- -- -- -- -- --
30: -- -- -- -- -- -- -- -- -- -- -- -- -- -- -- --
40: 40 41 42 43 -- -- -- -- -- -- -- -- -- -- -- --
50: -- -- -- -- -- -- -- -- -- -- -- -- -- -- -- --
60: -- -- -- -- -- -- -- -- -- -- -- -- -- -- -- --
70: -- -- -- -- -- -- -- --

But when I use both the PiSugar together with Waveshare 4-Channel INA219 HAT on my raspberry pi zero w,
the I2C bus doesnt work any more. So the Waveshare 4-Channel INA219 HAT and the PiSugar2 on my raspberry pi zero w
is not working anymore:
pi@zeropi:~ $ sudo i2cdetect -y 1
     0  1  2  3  4  5  6  7  8  9  a  b  c  d  e  f
00:          -- 04 -- 06 07 -- 09 0a -- 0c -- 0e 0f
10: -- -- 12 13 14 -- -- 17 18 -- -- -- 1c 1d 1e --
20: -- 21 22 23 -- -- 26 -- -- -- 2a 2b 2c -- -- 2f
30: 30 31 -- 33 34 -- -- -- 38 -- -- -- 3c 3d 3e --
40: 40 41 42 43 -- 45 46 47 -- -- -- 4b 4c -- -- 4f
50: 50 -- -- -- 54 55 56 -- -- 59 5a -- -- -- 5e 5f
60: -- -- 62 63 64 -- -- -- 68 69 -- -- -- -- 6e 6f
70: 70 -- 72 73 74 -- -- --
Is there any solution for my problem ?
Thanks in advance !

ahmed-mans, 2021-09-10:
Normally, as the i2c adresses are different it should be working fine. In my case I put the devices in different i2c ports and it worked. Now I don't know if it is possible in your case since you have a HAT device.

chickenherb, 2021-09-10:
Thank you for your reply,
as you can see the I2C device adresses are different. My hat uses 40, 41,
42 and 43.
This is different to the PiSugar2 used ones.
But when I scan the I2C bus with bot devices mounted then the bus scan
results in crazy found adresses and I can Not operate any I2C device.

Tanks a lot for your reply

Chickenherb

ahmed-mans ***@***.***> schrieb am Fr., 10. Sep. 2021, 12:09:

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

jonhaun, 2022-01-11:
I've experienced this too. (PiSugar2, RPI zero W, [https://ozzmaker.com/berrygps-berrygps-imu-quick-start-guide/](BerryGPS-IMU))

The IMU uses:
- 0x6A for the gyroscope and accelerometer
- 0x1C for the magnetometer
- 0x77 for the pressure sensor
- 0x42 for GPS

The RPI+Sugar works great on its own. As does the RPI+IMU.

Combining them (RPI+Sugar+IMU) causes weird behavior. If I call i2cdetect multiple times. The IMU registers seem to persist, but disappear intermittently, and register 75 for the Sugar is pretty much always gone,

I'd appreciate any help. My next debug focus will be the baud rate.

Tetsujinfr, 2022-04-03:
> Normally, as the i2c adresses are different it should be working fine. In my case I put the devices in different i2c ports and it worked. Now I don't know if it is possible in your case since you have a HAT device.

@ahmed-mans what do you mean by "I put the devices in different i2c ports and it worked" ? On different i2c pins? If yes which ones please?

Thanks

Closed 2024-08-06.

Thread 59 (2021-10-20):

PiSugar 2 & On Power Restore

jpcetre, 2021-10-20:
Hi,
I am playing with my new PiSugar2 (2 leds) and a Pi Zero W.
I expected to use it as an UPS and found the On Power Restore option for the Schedule Wake Up, but I am not able to make it work.
Any trick I should know?
(I tried to plug sugar and pi on 2 separate chargers but same result)

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

JdaieLin, 2021-11-28:
@wlmh110

wlmh110, 2021-12-03:
Hi,
Can it start up once? Or does it never starts up after shutdown?

erlendv, 2022-01-14:
@wlmh110 Im experiencing the same thing. Just purchased pisugar2. I selected the on power restore option. After shutting the pi down, disconnected and reconnected power, nothing happens. A couple of things I noticed:
- after booting the pi (turning pisugar off and on) and going into the web interface a warning pops up that I have turned off wake-on-power-restore and the setting in the UI turns back to disabled
- however, in /etc/pisugar-server/config.json `auto_power_on` is `true`

xlla, 2022-03-04:
I don't know where to ask a question, so post it here:
Can I use same power supply to charge the Pi and PiSugar while using feature "On Power Restore" ?
My purpose is when I turn on the power my device and Pi & PiSugar will be power on and start charge the PiSugar, when I turn  off the power , Pi will notice that and power off auto.

wlmh110, 2022-03-05:
> I don't know where to ask a question, so post it here: Can I use same power supply to charge the Pi and PiSugar while using feature "On Power Restore" ? My purpose is when I turn on the power my device and Pi & PiSugar will be power on and start charge the PiSugar, when I turn off the power , Pi will notice that and power off auto.

You need to use different chargers, otherwise PiSugar will charge itself by battery

wlmh110, 2022-03-05:
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

We suspect it is a software bug. What version of software are you using now?

Tetsujinfr, 2022-04-03:
@erlendv do you still experience that issue with the on pwr wake up function? If not, how did you fix it? (Software update, other?)

bluefireexplosion, 2022-06-24:
Still experiencing this issue with a pisugar 2, auto_power_on is enabled. When shutting down the pi, removing power, then reconnecting power, the pi will not turn back on until the power switch is toggled. Any solutions?

wlmh110, 2022-07-05:
> Still experiencing this issue with a pisugar 2, auto_power_on is enabled. When shutting down the pi, removing power, then reconnecting power, the pi will not turn back on until the power switch is toggled. Any solutions?

First, please update the latest software
Secondly, can you describe what happened after the external power supply was restored?

kcmd, 2023-06-10:
> > Still experiencing this issue with a pisugar 2, auto_power_on is enabled. When shutting down the pi, removing power, then reconnecting power, the pi will not turn back on until the power switch is toggled. Any solutions?
>
> First, please update the latest software Secondly, can you describe what happened after the external power supply was restored?

I'm experiencing the exact same problem described by bluefireexplosion. The latest software is installed. Being able to automatically turn the Raspberry Pi on again after power has been restored is an important capability for remotely installed devices that are being recharged by a solar panel.

kcmd, 2023-06-10:
Likely relates to Issue #98.

Closed 2024-07-26.

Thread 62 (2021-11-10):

Qi used as 5V VIN but not charging

pauloesperon, 2021-11-10:
Hi there, I would like to use the Qi pads to wire a USB-C female breakout board 5v input to I can put the charging port somewhere else on my enclosure instead of using the micro USB port. I wired it but it is not charging. Any idea what might be happening?

As far as my wiring, from the break out board I connect the VBUS and GND to + and - Qi.

Thank you!

JdaieLin, 2021-11-28:
@wlmh110

wlmh110, 2021-12-03:
Could you please take a picture?

dbrb2, 2021-12-31:
Should this work? I was hoping to do the same, but haven't yet wired it up...

wlmh110, 2022-01-04:
As long as 5V power supply is input, it can work

nachotisnes, 2022-02-06:
Did you manage to get this working? I'm facing the same issue. Sorry in advance if I make newbie errors, i'm kinda outside my comfort zone here.

I've been doing some measuring with my multimeter, and I'm getting the idea that the correct wiring may be the opposite one.

My measurements are:
- When the QI adapter is not plugged to the board and is "active", the voltage is 4.92
- When the QI adapter is wired as you mention, the output voltage from the adapter drops to ~0.3, and the adapter starts working erratically: it seems to be turning on and off.
- In that case, the battery is shown as "not charging" and continues discharging using the webUI, although using the command line sometimes I get a battery_charging=true.

@wlmh110 can you make something of this?

wlmh110, 2022-02-07:
Hi, can you take a picture of the system?

nachotisnes, 2022-02-07:
It was a dumb mistake in my part.

Seeing the pics I posted eariler y realized my mistake, I had the wires inverted (VIN/GND).

After correcting that the web UI shows a "Charging" status. Will continue my testing.

Thanks!

Closed 2024-07-26.

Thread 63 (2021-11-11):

I2C Conflicts with other devices

mlaity, 2021-11-11:
This has been brought up a couple times in the past, but no response from PiSugar support, I've only seen responses from other users in the community.

I'm using a Raspberry Pi 4B, OzzMaker BerryGPS-IMU-4, and PiSugar 2 Pro.  When both devices are connected, the I2C addresses continually come and go for each device, visible via continual i2cdetect scans, making both devices inaccessible. There does not seem to be a conflict in I2C addresses between these devices, with the BerryGPS-IMU-v4 using 1c, 6a, and 77, and the PiSugar using 32 and 75.  This doesn't seem to be an issue with the BerryGPS-IMU. Their support forums only had one complaint of this issue, but it was also in conjunction with a PiSugar.  We have used other I2C devices with the BerryGPS-IMU without trouble.  Seems to be something specific to the PiSugar.

We can't just create additional I2C buses as both devices have built-in headers to connect to I2C Bus 1 on Pi Pins 3 and 5.  This has been the common path forward for others experiencing this problem, but I am just up against the hardware/pin layout of each device.

JdaieLin, 2021-11-28:
Hi, we think it's a limitation of PiSugar2's I2C feature which provided by the power chip. You can contact pisugar.zero@gmail.com for the coming PiSugar3 with an independent MCU.

eqikkwkp25-cyber, 2022-09-10:
Hello, is this kind of issue solved with the available PiSugar3?

Unfortunately as a PiSugar2 owner i am not very happy with this kind of 'design issues', in my case its an EPaper HAT in combination with PiSugar2 and a Raspberry Pi Zero2: [[Errno 121] Remote I/O error](https://github.com/waveshare/Touch_e-Paper_HAT/issues/10#issuecomment-1141375782). I already checked with another Pi Zero2 but i observe the same issue there.

Any workaround how i could resolve this?

spaceman1988, 2023-04-29:
If you're adding a HAT that uses i2c (like a sound card) the PiSugar S has a switch that turns off i2c (meaning it doesn't hold CPIO3 (pin 5) in "low" killing i2c communications. That feature works, BUT... if your setup is going in a case accessing the tiny buttons on the PiSugar board to turn the Pi back on isn't possible. You can turn off the Pi by assigned an unused CPIO to a pushbutton to turn off the Pi, but in a case there's no way to turn it back on. Pulling the power doesn't work since battery power is still available. Since most folks put their Pi in some sort of case this is a major issue with the PiSugar's design.

Closed 2024-07-26.

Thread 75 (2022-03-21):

Pisugar3 Plus docs and datasheet

Tetsujinfr, 2022-03-21:
Hi

I can not find much, if any, real documentation about the Pisugar3 Plus. How to use it? What are the board buttons and plugs functions?
E.g. what is the small round button on the back of the board? An "activate" bitton? If I do not press it, the board does not power up, really no convenient. Not reference of this button is to be found for the pisugar 3 plus.
What about the extra microUSB plug? Is it an alternative charging plug if one soes not want to use the USB-c plug? Is it another charging plug in parallel of the usb-c one? Is it a power source to power peripherals? No info.

Thanks for your help to one of your customer.

Tetsujinfr, 2022-03-24:
Anyone from pisugar?

JdaieLin, 2022-03-26:
The small round button on Pisugar3 is for reset. It seems abnormal if you have to press it before power up. Please contact our product support email for more detail.
The microUSB plug is an alternative charging plug.
More detail document please refer to:
https://github.com/PiSugar/PiSugar/wiki/PiSugar-3-Series

Tetsujinfr, 2022-03-26:
I have seen this page, it is not realky a documentatiin, rather a sales pitch of the features of the bord.
For instance, it boasts a "anti-mistaken touch button": but does not indicate where and what it is. Does it refer to the small round button in the back of the board? (Which was already present on pisugar pro2 and is a pain to deal with?)
It mentions a changeable i2c address: cool but how do you do it in practice? A code/instructions example would be more useful.
It mentions the rtc which can hold time about 1yr without battery: it may but when I had my battery ran out of juice, after restarting my rpi, but still being off internet connection, the rtc clock was significantly off from the real time.

I am considering reverting back to the pi sugar pro2 and using a separate i2c transmuxer to deal with i2c adresses conflicts I had with it. The glue of the magnet attached to the battery went loose, and when opening my prototype case I found the battery hanging with it power cable, the two magnets clamped on the board on there own... the temperature of the cpu somewhat spread to the magnet and got the glue to fail binding it. The magnet thing is a smart diy design but not robust enough for real projects I am afraid. I may have the same issue with the pisugar pro2 but at least now I know about it.

Tetsujinfr, 2022-03-26:
By the way, you may want to test the behaviour of the pisugar3 plus when using a power button connected on pin 5 and 6. For me, whan I shutdown my rpi, it does cut power fully on the board, hence impossible to wake it up by pressing the button (which connect pin 5 and pin 6).
Only way to get the power back it to press the infamous small round rest button that no one asked for and which is not documented on your wiki page yet.

Tetsujinfr, 2022-04-03:
Ok so, I have pligged my pisugar onto a different raspberry pi3b+ to test it more easily.
Below, I describe my setup and the scenario that I would like to happen, versus what is happening for real, so that you can tell me if it is expected or I am doimg something wrong.

Setup:
My pisugar3+ is connected to a power source via its micro usb power connector (the usb-c power connector is not connected to anything).
The raspberry micro usb pi power is NOT connected to any power source.
The pisugar3+ batterry is charged.
The rpi power leds are idle at that point, even if I press the pisugar3+ small power button. The only way I found to power up the rpi is to press the tiny very small circular button on the back of the pisugar3+ (after pushing the battery so that I can press the btn with my finger).
So I press this tiny round button and the rpi starts up.
Now, if I shutdown the rpi properly, via the OS main menu "shutdown" option, the completely shutsdown, the power leds turns off on the rpi pcb. So, I can not use a powerup button  to wake up the rpi, e.g. through the usual way of shorting pin 5 and 6 via a swith button.
If I press the small "pwr" of the pisugar3+ the rpi does not power up neither.
The only way for me to power up the rpi again, is to press the tiny round button on the back of the pisugar3+ : this is a nightmare to access and I do not see the point of having the "pwr" button on the pisugar3+ pcb then. The only thing the "pwr" button does, is to indicate the charging level of the battery, and to shut down the rpi if I press it for long (again, total power cut on the rpi board, all leds turned off on the rpi).

Expected behavior: to have the rpi led turned ON at all time, i.e. if I shut down the rpi through software, the rpi pcb is still under tension, its red power led is still ON and I can wake up the rpi via shorting pin 5 and 6.
If the pisugar3+ has been turned off via a long press of the "pwr" button, to be able to power it back ON bu pressing the "pwr" button again.

Please not that I did upgrade the pisugar3+ firmware with the latest version available as soon as I installed it. The upgrate was marked as succesfull.

fheslouin, 2022-04-04:
@Tetsujinfr did you look for anti mistaken touch function in 6. of https://github.com/PiSugar/PiSugar/wiki/PiSugar-3-Series ?
-> 1 short press followed by 1 long press (5s) to start up the board.

I dislike this behavior but this is the way to start the board, you can disable this function by software but it is reset each time the battery is disconnected or empty :(

Tetsujinfr, 2022-04-04:
@fheslouin thanks for your comment.

Tbh what I need is to make sure the rpi pcb is always under tension so that I can turn it back on if it has been shutdown properly by software.
On the WebGUI of the pisugar, there is a small comment font size 2 where it mentions that if one wants to power the rpi through its power connector (which for me is the only way so far I can make sure the rpi pcb will stay under tension), and the pisugar through its power connector at the same time, then two different adapters have to be used, otherwise the pisugar will charge itself.
So I am setting up a second adapter.
I do not want my users to have to mess around with the tiny pisugar buttons (my project has the rpi in a closed box, so no access to the pisugar buttons anyways.

I thought the pisugar was a self sufficient UPS solution to cover all scenarios properly, but so far it is not for me.

mitpre, 2022-08-01:
@Tetsujinfr I'm also developing something, that would need the 'self sufficient UPS solution' without the need to access pisugar buttons. Did you maybe find a solution?

kjus, 2023-03-07:
So no datasheet? I'm also struggling with some features.

danielmorozoff, 2023-07-03:
@JdaieLin Do you guys have a component specs and datasheet ? Could you please share it.

Thanks

StephenGrable1, 2024-05-04:
@wlmh110 is the recommended documentation for the PiSugar 3 plus [here](https://github.com/PiSugar/PiSugar/wiki/PiSugar-3-Series#function-specifications)? or does that differ significantly from pisugar 3?

Tetsujinfr, 2024-05-04:
> @Tetsujinfr I'm also developing something, that would need the 'self sufficient UPS solution' without the need to access pisugar buttons. Did you maybe find a solution?

Sorry, did not see your question.
So I gave up on the pisugar products. Too messy to deal with, no proper doc or support, including here on github. It is for small diy projects and even so good luck. It is not robust for slightly challenging conditions, like in a case where temps would go in the 40C-45C, given the glue of the magnet just looses its properties.

I did test the [waveshare HAT](https://www.waveshare.com/ups-hat-c.htm) for rpi zero, and works well, fyi.

I did not try their rpi 3-5 UPS product yet, but I would try that first if I was considering redoing a new prototype which requires power outage resiliency.

I am done with PiSugars I am afraid.

Closed 2024-07-09.

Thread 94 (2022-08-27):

PISugar3 Case issues

TomDII, 2022-08-27:
Wanted to mention that the PISugar3 case files for download  have issues.
#1 The 4 charging lights are on the same side as the switches now.  Case it's on the end.
#2 The power button does not have the recessed space like the other button so when you assemble the case the power button is pushed down.

JdaieLin, 2022-08-28:
Thanks for the feedback. I had fixed them in the latest commit.

TomDII, 2022-08-28:
Thanks, printed and worked perfect.  Buttons are a little sloppy, I scaled them up .5mm x and y. And fits perfect. 112.5% and 105% if anyone wants to try.

Closed 2022-08-28.

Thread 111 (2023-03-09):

Mounting Problem with Pi4

tomschlde, 2023-03-09:
Question:
I printed the case from the repo and tried to insert the completely assembled (Pisugar2 pro & RPI4) into the case - this did not work.
Is it correct that the assembly has to be done in 2 parts and that the PiSugar and the Rpi4 are first joined together inside the enclosure so that the clips on the side of the enclosure are pinched between the PCB of the RPi4 and the PiSugar?

TIA
Thomas

JdaieLin, 2023-05-03:
Hi Thomas, it's correct as you described. The clips on the side of the enclosure are pinched between RPi4 and the PiSugar

Closed 2024-06-06.

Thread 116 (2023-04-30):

Please Define PiSugar S CTRL-OFF-ON Pad Usage

spaceman1988, 2023-04-30:
Request a better definition of the PiSugar S CTRL-OFF-ON Pads:

1. Do these pads control power from the PiSugar to the Pi?
2. Do these pads in any way connect to or effect the GPIO pin functions?
3. Do the pads perform the same function as the adjacent small on-off slide switch?
4. If the pad are wired to an external switch does the external switch override the slide switch on the board?
5. If an external switch is connected to the pads should the slide switch on the board be placed in the "on" or "off" position?
6. What rating should an external switch have as a minimum?
7. Can you turn ON the Pi by connecting CTRL and OFF to a momentary pushbutton switch while leaving the slide switch on the board in the "ON" position.

wlmh110, 2023-05-04:
Before answering your questions one by one, let me explain the working principle of the power switch. These three pads and the adjacent slide switch are used to control a load switch to turn on or off the power supply. The CTRL pin is directly connected to the control pin of the load switch. When it is connected to the ON pad, it represents a high level (connected to the battery positive through a 10K resistor), while it represents GND when connected to the OFF pad. Due to the existence of the 10K resistor, connecting to GND will have a main effect.

These interfaces control the power supply from PiSugar to the Raspberry Pi.

These interfaces do not connect to or affect the GPIO pin functions.

These interfaces perform the same function as the adjacent small on-off slide switch, and both can control the power supply.

When these pads are connected to an external switch and used together with the slide switch, any of the switches being closed will turn off the power output.

If using an external switch with a self-locking function, the slide switch should be placed in the "ON" position. If the external switch does not have a self-locking function, the slide switch should be placed in the "OFF" position.

The switch itself does not carry current, so there is no specific requirement for it.

You can turn on the Pi by connecting CTRL and OFF to a momentary pushbutton switch while leaving the slide switch on the board in the "ON" position. This will briefly cut off the power and then restore it, thereby waking up the Raspberry Pi. However, we recommend using the custom switch to wake up the Raspberry Pi, which works by briefly pulling the SCL pin low. This is a recommended way to wake up the Raspberry Pi while keeping the power supply connected.

spaceman1988, 2023-05-08:
I appreciate this very precise answer - exactly what I needed.

The PiSugar S provides many options so following PiSugars advice to use the
'S' was a great solution.

The problem with using the GPIO3 pin was caused by the low power state on
the Pi board. I am using a Pi4B which has a Low Power Mode that leaves on
the 5v line functional - the GPIO3 is not monitored. It took me some time
to realize why momentarily shorting GPIO3 wouldn't generate a restart. I'm
not sure why my Pi4 was defaulted to Low Power Mode but I modified the boot
sequence to instruct the Pi to go into a normal shutdown/halt mode
which preserves GPIO3 functionality. Once I accomplished that I was able to
restart the Pi using a momentary short of GPIO3 to ground. It's nice to
know that if a Pi4 owner wants to use Low Power Mode the PiSugar S provides
that capability through the CTRL-OFF pads.

Thank You.

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

Closed 2024-06-22.

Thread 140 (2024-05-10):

PI Sugar 2 XL Case STL

mikeacre, 2024-05-10:
It seems that the metal pieces glued to the PiSugar2 board combined with the 3d printed peices that hold the boards together within the case, make the boards too far apart for the contacts to touch.

Am I supposed to remove the metal threaded pieces or am I just missing something or is this a flaw?  maybe there should just be a divider in the middle instead of the holed supports?

Printed:
https://github.com/PiSugar/PiSugar/blob/master/model2/pisugar2_shell_xl.STL

**Note:** This repo is mainly about the entire PiSugar project, cases and wiki. We usually process these issues once a month. For quick response about PiSugar products, please contact pisugar.zero@gmail.com. For software issues, please submit your issuse to https://github.com/PiSugar/pisugar-power-manager-rs/issues

mikeacre, 2024-05-10:
Actually it appears I didnt print the pi sugar 2 stl

Closed 2024-05-10.

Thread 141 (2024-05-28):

How to connect a PiSugar 3 to a Pi Zero 2W without mounting them directly to each other?

Manish181992, 2024-05-28:
Hi,

I want to mount my Pi Sugar 3 separate from my Pi Zero 2W. How do I connect the two? My guess is to use the extension interface on PiSugar 3, but what type of connector does it use?

**Note:** This repo is mainly about the entire PiSugar project, cases and wiki. We usually process these issues once a month. For quick response about PiSugar products, please contact pisugar.zero@gmail.com. For software issues, please submit your issuse to https://github.com/PiSugar/pisugar-power-manager-rs/issues

JdaieLin, 2024-05-28:
connect the extension interface to pizero:
5V Output -> Pi 5V
GND -> Pi GND
SDAT -> Pi I2C1 SDA (GPIO2)
SSCL -> Pi I2C1 SCL (GPIO3)

Manish181992, 2024-05-28:
What type of connector can I use for the extension interface?

JdaieLin, 2024-06-06:
6Pin with 1.75mm pitch

Closed 2024-05-28.

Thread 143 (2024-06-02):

PiSugar2 Portable 1200 - External Power Button

ranasats, 2024-06-02:
I want to connect an external power button to the PiSugar2 Portable for my rpi zero. Can someone provide the pins which should be connected to a switch in order to accomplish this? I would like to put the zero in a case and I wouldn't have easy access to the standard power switch anymore. The switch I have is a normal on-off switch: https://www.adafruit.com/product/482

The documentation from the other 'issues' here: https://github.com/PiSugar/PiSugar/issues/116 say that for the S model there are ctrl on off pads. I don't see those pads on the Sugar Portable.

Thanks, @wlmh110 for your help :)

**EDIT**
Testing I found these two pads in red, when either one is connected to the ground pad, will turn OFF the pisugar while the switch is in the ON position. I want to confirm that bridging one of those with the ground won't cause any harm for extended period of time.
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

JdaieLin, 2024-06-05:
Here are the instructions for connecting an external switch to the PiSugar2:

Turn the switch to the ON position.

Solder three pads as shown in the diagram below.

When 1 and 2 are connected, the device will turn on. When 2 and GND are connected, the device will turn off.

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

Don't worry about a short circuit when 2 and GND are connected. The switch uses a pull-up resistor, so the current is very small when 2 is connected to GND.

Closed 2024-06-05.

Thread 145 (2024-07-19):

support for pi 5 for 5A max output

beitong95, 2024-07-19:
**Note:** This repo is mainly about the entire PiSugar project, cases and wiki.
We handle issues via email. If you have any questions about PiSugar products, please contact us at pisugar.zero@gmail.com and we will respond promptly. For software code issues, please submit your issuse to https://github.com/PiSugar/pisugar-power-manager-rs/issues

JdaieLin, 2024-07-22:
Hi there, PiSugar3 Plus can provide a maximum current output of 3A, which mainly depends on the output capacity of the current lithium battery and the maximum current allowed by the wire. If you want to achieve the output requirement of 5A, you may have to reduce the voltage by reducing the high voltage, which will be a completely new circuit design.

JdaieLin, 2024-07-22:
It is difficult for lithium batteries in portable devices to meet this requirement.

Closed 2024-07-23.

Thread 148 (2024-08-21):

PiSugar 3 Software Power Off Doesn't Fully Power Off System

LouisLenoir4, 2024-08-21:
**Description:**
I am using a PiSugar 3 with a Raspberry Pi 4 and I'm experiencing an issue with the software power off feature. When I click the power off button, the Raspberry Pi 4 shuts down, but the PiSugar 3 battery keeps powering the system.
The LEDs are still emitting light, and the fan is still running, even though the Raspberry Pi 4 is powered off. Additionally, I am not able to restart the Raspberry Pi 4 using the buttons on the PiSugar 3.
I have updated the PiSugar server and firmware to the latest version (1.7.7), but the issue persists.
**Environment:**

PiSugar 3
Raspberry Pi 4
PiSugar server and firmware version 1.7.7

Steps to Reproduce:

Connect the PiSugar 3 to the Raspberry Pi 4.
Set the power off mode to "soft poweroff"
Click the power off button on the PiSugar 3.
Observe that the Raspberry Pi 4 shuts down, but the PiSugar 3 battery continues to power the system.
Attempt to restart the Raspberry Pi 4 using the PiSugar 3 buttons.

Expected Behavior:
When the power off button is clicked, the entire system (Raspberry Pi 4 and PiSugar 3) should power off completely, and I should be able to restart the Raspberry Pi 4 using the PiSugar 3 buttons.
Actual Behavior:
The Raspberry Pi 4 shuts down, but the PiSugar 3 battery continues to power the system, with the LEDs and fan still running. I am unable to restart the Raspberry Pi 4 using the PiSugar 3 buttons.
Workaround (if any):
I have not found a reliable workaround for this issue.
Additional Information:
The hardware power off feature works as expected, but it is too dangerous for the databases on my device, so I need to use the software power off feature.

JdaieLin, 2024-10-04:
It seems to be an issue of pisugar-poweroff.
@fengyc

JdaieLin, 2024-10-07:
If you directly use the shutdown command to turn off the Pi4, will the PiSugar also shut down afterward?

JdaieLin, 2024-10-07:
Is this a consistently reproducible issue or does it occur sporadically?

JdaieLin, 2024-10-07:
If you encounter this issue again, please paste the OS log here. After booting up, use journalctl -u pisugar-poweroff -n 100 to check if there were any I2C errors before the last shutdown.

Closed 2024-11-21.

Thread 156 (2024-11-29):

power off question

mtlmaks, 2024-11-29:
Hi, I have a raspberry pi 4 on a pisugar 3 board with its battery, with the pisugar and the rpi both connected to 5v power. When no power is connected and I shut down the rpi under rpi os, it shuts completely down, i.e. not lights anymore on the rpi. This way, when reconnecting power to the boards, the rpi starts up as the wake up setting in the pisugar power managment settings is set to power restore.
Now, when I run the rpi under [Volumio OS](https://volumio.com/get-started/), which is based on rpi os, the rpi does not completely shut down when no power is connected, with still a red light on on the rpi, so it still draws power from the battery as it seems. This also prevents the rpi to start up when power is restored.  Any idea how to solve this, either how to completely shut down the rpi under volumio, or how to have it reboot when power is restored? Any help would be highly appreciated! Thanks! :)

JdaieLin, 2024-12-10:
Had you pisugar-poweroff together with pisugar-server on your OS?

mtlmaks, 2024-12-11:
Hi, I'm not sure what you mean by installing pisugar-poweroff... I installed the `pisugar-power-manager`... But like I said, the pi4 shuts down completely under `Raspbian/Raspberry Pi OS`, but not under Volumio. This seems to be the same issue as in this post: https://github.com/PiSugar/PiSugar/issues/148

JdaieLin, 2024-12-12:
You can find the pisugar-poweroff package here: [pisugar-poweroff_1.7.8-1_armel.deb](https://github.com/PiSugar/pisugar-power-manager-rs/releases/download/latest/pisugar-poweroff_1.7.8-1_armel.deb). It's a plugin to make sure the shut down completely.

mtlmaks, 2024-12-12:
Thanks. I tried that, installed https://github.com/PiSugar/pisugar-power-manager-rs/releases/download/v1.7.7/pisugar-programmer_1.7.7-1_armhf.deb, rebooted, but the rpi still doesn't shut down completely under Volumio... I did get a warning at the end of the install progress, that raspi-config wasn't found, which does not exist under Volumio, not sure if that could have an impact...

mtlmaks, 2024-12-13:
Oh snap, I just noticed that I installed the wrong package... Sorry about that, will try again and report back.

JdaieLin, 2024-12-13:
It should access the raspi-config to enable i2c interface, but raspi-config only exist on Raspbian. In this case you should find a  way to enable i2c on Volumio OS, then make sure which i2c bus the PiSugar is using on your system. To custom the i2c bus you can modify in /etc/pisugar-server/config.json

JdaieLin, 2024-12-13:
you can run
```
 ls /dev/i2c*
```
to check the i2c bus list on Volumio

mtlmaks, 2024-12-13:
Hi, first of all, thanks for trying to help me :)
The i2c bus seems to be set correctly as far as I can see, not sure however if `"i2c_addr"` should be null...:

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

JdaieLin, 2024-12-21:
Had you choose the pisugar model during the pisugar-server installation? Some config values depends on the model.

JdaieLin, 2024-12-22:
I guess the installation of pisugar-server on Volumio OS didn’t go very smoothly, which resulted in some missing parameters.

Closed 2025-02-04.

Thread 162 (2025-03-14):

[Pisugar 3] Battery not charging

max1mvs, 2025-03-14:
I have a brand new Pisugar 3 installed on a Raspberry Pi® Zero 2 WH running Raspberry Pi OS Lite (32‑bit). I installed all the relevant files for it and can get the server up and running. But the battery seems to constantly be at 0% while the green lights continually flash while charging.
I cannot get any information from the shell, and I keep running into errors saying "Invalid request." when trying commands such as `echo "get battery" | nc -q 0 192.168.x.x 8423`.  Trying to update the firmware using `curl https://cdn.pisugar.com/release/PiSugarUpdate.sh | sudo bash` also returns errors:

`  % Total    % Received % Xferd  Average Speed   Time    Time     Time  Current
                                 Dload  Upload   Total   Spent    Left  Speed
100  1553  100  1553    0     0   2300      0 --:--:-- --:--:-- --:--:--  2304
--2025-03-14 10:16:04--  https://cdn.pisugar.com/release/PiSugar3Firmware/fm33lc023n/pisugar-3-application.bin
Resolving cdn.pisugar.com (cdn.pisugar.com)... 47.246.48.224, 47.246.48.225, 47.246.48.226, ...
Connecting to cdn.pisugar.com (cdn.pisugar.com)|47.246.48.224|:443... connected.
HTTP request sent, awaiting response... 200 OK
Length: 23100 (23K) [application/octet-stream]
Saving to: ‘/tmp/pisugar-update.HbNT36v/pisugar-3-application.bin’

/tmp/pisugar-update.HbNT36v/pisugar-3-application.bin        100%[===========================================================================================================================================>]  22.56K  --.-KB/s    in 0.03s

2025-03-14 10:16:04 (897 KB/s) - ‘/tmp/pisugar-update.HbNT36v/pisugar-3-application.bin’ saved [23100/23100]

Stoping pisugar-server...
[2025-03-14T09:16:04Z INFO  pisugar_programmer] WARNING:
[2025-03-14T09:16:04Z INFO  pisugar_programmer] 1. PLEASE CONFIRM THAT THE BATTERY IS FULLY CHARGED
[2025-03-14T09:16:04Z INFO  pisugar_programmer] 2. SYSTEMD SERVICE pisugar-server MUST BE STOPPED
[2025-03-14T09:16:04Z INFO  pisugar_programmer] OTHERWISE UPGRADE MAY NOT SUCCEED!!!
[2025-03-14T09:16:04Z INFO  pisugar_programmer] CONFIRM? (y or n):
[2025-03-14T09:16:04Z INFO  pisugar_programmer]
[2025-03-14T09:16:04Z INFO  pisugar_programmer] Firmware size: 23100
[2025-03-14T09:16:04Z INFO  pisugar_programmer] PiSugar bootloader/bootapp not ready, please reset or wait, retry...
[2025-03-14T09:16:04Z INFO  pisugar_programmer] PiSugar bootloader/bootapp not ready, please reset or wait, retry...
[2025-03-14T09:16:04Z INFO  pisugar_programmer] PiSugar bootloader/bootapp not ready, please reset or wait, retry...
[2025-03-14T09:16:04Z INFO  pisugar_programmer] PiSugar bootloader/bootapp not ready, please reset or wait, retry...
[2025-03-14T09:16:05Z INFO  pisugar_programmer] PiSugar bootloader/bootapp not ready, please reset or wait, retry...
[2025-03-14T09:16:05Z INFO  pisugar_programmer] PiSugar bootloader/bootapp not ready, please reset or wait, retry...
[2025-03-14T09:16:05Z INFO  pisugar_programmer] PiSugar bootloader/bootapp not ready, please reset or wait, retry...
[2025-03-14T09:16:05Z INFO  pisugar_programmer] PiSugar bootloader/bootapp not ready, please reset or wait, retry...`

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

How do you troubleshoot this?

Cheers,
Massimo

JdaieLin, 2025-03-14:
Hi Massimo,

looks like the i2c is not connect so there's not data and cannot be upgrade.
You can use `i2cdetect -y 1` to check if there's i2c device. If not please try following the first FAQ:
https://github.com/PiSugar/PiSugar/wiki/FAQ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

max1mvs, 2025-03-14:
I appreciate your help.

I tried to scrape a bit on the solder points and reattached the Pisugar 3. But that didn't work. I can get the battery to start and run the Raspberry Pi, but the problem is the same. Using `i2cdetect -y 1` I get:

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

Cheers,
Massimo

max1mvs, 2025-03-16:
Is there any way to troubleshoot this and determine if the unit is defective so I may return it to where I bought it for a replacement?

JdaieLin, 2025-03-19:
Hi Massimo,

Since you have already tried but I2C is still not working, it could be an issue with the PiSugar pins. You should contact our product support via email to check if a product replacement is needed.

max1mvs, 2025-03-20:
Thanks! I tried a couple of more times to "clean" the soldering at the back of the Pi, and now I was able to upgrade the firmware successfully. Does this seem correct now?

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

Closed 2025-03-20.

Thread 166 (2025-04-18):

how to connect usb output

openmotion, 2025-04-18:
hello
i would like to power an android device instead of a raspberry
can i use 5v out , where must i connect the V+ V- of the usb cable ?

JdaieLin, 2025-04-30:
Hi, i think it should be: 5v out -> V+ , GND -> V-

Closed 2025-06-14.

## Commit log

2018-12-23 update 3D printed model
    [battery900.SLDPRT, pisugar.SLDPRT, pisugar_bw2.dwg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]
2018-12-28 case update
    调整了电路板卡口位置
    增加排针开口的盖子
    [pisugar_case_pin_cap.SLDPRT, pisugar_case_pin_cap.STL, pisugar_case_shell.SLDPRT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]
2019-01-09 lcd and camera cap
    新增加了1.3寸显示屏外壳、摄像头外壳。未验证
    [1.3inch_lcd_hat.SLDPRT, camera.SLDPRT, pisugar_case_all.SLDPRT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]
2019-01-10 New caps for camera and 1.3inch LCD ！！
    [comp.SLDASM, pisugar_case_camera_cap.SLDPRT, pisugar_case_common_cap.SLDPRT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]
2019-01-10 camera cap and lcd cap stl
    [pisugar_case_camera_cap.SLDPRT, pisugar_case_camera_cap.STL, pisugar_case_lcd_cap.STL]
2019-01-11 folder change
    [ReSpeaker 2-Mics Pi HAT.skp]
2019-01-14 fix size of camera/pin/lcd cap
    [comp.SLDASM, pisugar_case_camera_cap.SLDPRT, pisugar_case_camera_cap.STL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]
2019-01-20 export shell stl
    [pisugar_case_shell.STL, pisugar_case_shell_xl.STL]
2019-01-21 fix 1.3inch lcd cap
    [comp.SLDASM, pisugar_case_lcd_cap.SLDPRT, pisugar_case_lcd_cap.STL]
2019-01-21 respeaker model
    [ReSpeaker_2-Mics_Pi_HAT.SLDPRT, comp.SLDASM]
2019-01-21 respeaker cap draft
    [comp_respeaker.SLDASM, pisugar_respeaker_cap.SLDPRT]
2019-01-22 re-export & respeaker cap test
    [ReSpeaker 2-Mics Pi HAT.skp, ReSpeaker_2-Mics_Pi_HAT.SLDPRT, comp_respeaker.SLDASM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]
2019-02-11 move files
    [1.3inch_lcd_hat.SLDPRT, ReSpeaker 2-Mics Pi HAT.skp, ReSpeaker_2-Mics_Pi_HAT.SLDPRT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]
2019-02-12 update camera port position
    更改了摄像头接口排线预留位置
    [pisugar_case_shell.SLDPRT, pisugar_case_shell.STL, pisugar_case_shell_xl.SLDPRT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]
2019-03-03 common_cap改为两边卡扣活动
    [pisugar_case_common_cap.SLDPRT, pisugar_case_common_cap.STL]
2019-03-03 update thin version of shell
    [pisugar_case_shell.SLDPRT, pisugar_case_thin_shell.SLDPRT, pisugar_case_thin_shell.STL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]
2019-03-09 update pin cap
    [pisugar_case_pin_cap.SLDPRT, pisugar_case_pin_cap.STL]
2019-03-12 基础版模型公差调整
    0.2公差兼容调整
    边框筋从1.5mm统一调整至1.3mm
    摄像头插口增高2mm
    通用盖子内边深度2.1mm调整至2.15mm
    待验证
    [pisugar_case_all.SLDPRT, pisugar_case_common_cap.SLDPRT, pisugar_case_common_cap.STL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]
2019-03-13 update common cap
    [pisugar_case_common_cap.SLDPRT, pisugar_case_common_cap.STL, pisugar_comp.SLDASM]
2019-03-21 nobatt shell
    [pisugar_nobatt_shell.SLDPRT, pisugar_nobatt_shell.STL, pisugar_thin_nobatt_shell.SLDPRT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]
2019-03-25 盖子内边圆角统一修改
    外圆角2.9 - > 3.3
    [pisugar_case_common_cap.SLDPRT, pisugar_case_common_cap.STL, pisugar_case_pin_cap.SLDPRT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]
2019-04-10 change button height
    [pisugar_case_button.SLDPRT, pisugar_case_button.STL, pisugar_case_button_comp.SLDPRT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]
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2019-04-27 holder fix
    [holder_asm.SLDASM, pisugar_holder.SLDPRT]
2019-05-06 shell bug fix
    [pisugar_case_shell.SLDPRT, pisugar_case_shell.STL, pisugar_comp.SLDASM]
2019-05-07 update holder model
    [pisugar_holder.SLDPRT, pisugar_holder.STL]
2019-05-07 thin shell bug fix
    [pisugar_case_thin_shell.SLDPRT, pisugar_case_thin_shell.STL, pisugar_case_thin_shell_xl.SLDPRT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]
2019-05-16 update holder
    shell_xl bug fix
    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
    [holder_asm.SLDASM, pisugar_case_shell_xl.SLDPRT, pisugar_case_shell_xl.STL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]
2019-06-04 fix shell
    [pisugar_case_shell.SLDPRT, pisugar_case_shell.STL]
2019-06-25 no-battery case update
    [pisugar_nobatt_shell.SLDPRT, pisugar_nobatt_shell.STL, pisugar_thin_nobatt_shell.SLDPRT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]
2019-07-04 thin shell fix
    [pisugar_case_thin_shell.SLDPRT, pisugar_case_thin_shell.STL, pisugar_case_thin_shell_xl.SLDPRT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]
2019-08-26 pin cap bug fix
    [pisugar_case_pin_cap.SLDPRT, pisugar_case_pin_cap.STL]
2019-09-11 bug fix
    [pisugar_case_common_cap.SLDPRT, pisugar_case_common_cap.STL, pisugar_case_pin_cap.SLDPRT]
2019-09-11 pisugar2 case model
    test
    [RaspberryPiZeroW.SLDPRT, comp.SLDASM, pisugar2Board.SLDPRT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]
2019-09-15 update pisugar2 test
    [comp.SLDASM, pisugar2_button.SLDPRT, pisugar2_button_batch.SLDPRT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]
2019-11-04 fix case
    [comp.SLDASM, pisugar2_button_batch.SLDPRT, pisugar2_button_batch.STL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]
2019-11-22 pisugar2 test
    [comp.SLDASM, comp2 - pisugar2_shell_xl-1.STL, comp2 - pisugar2_side_lid-1.STL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]
2019-11-30 add tf card hole
    [pisugar_case_shell.SLDPRT, pisugar_case_shell.STL, pisugar_case_shell_xl.SLDPRT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]
2019-12-21 update pisugar2 case beta
    [comp2 - pisugar2_shell_xl-1.STL, comp2 - pisugar2_side_lid-1.STL, comp2.SLDASM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]
2020-05-07 update case for pisugar2
    [comp.SLDASM, comp2.SLDASM, pisugar2Board.SLDPRT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]
2020-05-11 update common lid
    [pisugar_case_common_cap.SLDPRT, pisugar_case_common_cap.STL, pisugar_case_pin_cap.SLDPRT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]
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2020-09-23 add pisugar2 thin shell
    [pisugar2_shell_thin_xl.SLDPRT, pisugar2_shell_thin_xl.STL, pisugar2_shell_xl - pisugar2_shell_xl-1.STL]
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2020-10-08 update pro case beta
    [bottom.SLDPRT, comp.SLDASM, port-panel.SLDPRT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]
2020-10-25 update pro model beta
    [comp.SLDASM, port-panel.SLDPRT, pro-port-panel.STL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]
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2021-06-01 feat: add pisugar2 shell for 900mah
    [pisugar2_shell.SLDPRT, pisugar2_shell.STL]
2021-06-01 feat: add pisugar2 thin case for 900mah
    [pisugar2_shell_thin.SLDPRT, pisugar2_shell_thin.STL]
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2021-12-03 update: model 3 for zero
    [comp3.SLDASM, pisugar3 - pisugar3_shell_xl.STL, pisugar3Board.SLDPRT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]
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2022-02-06 update: pisugar 3 case for 4B
    [comp.SLDASM, port-panel-4b-2p.SLDPRT, port-panel-4b-3p.SLDPRT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]
2022-03-31 feat: add pisugar3 thin shell
    [pisugar3_thin_shell_xl.SLDPRT, pisugar3_thin_shell_xl.STL, pisugar_case_common_cap.SLDPRT]
2022-04-29 feat: pro model for 3b
    [Ras Pi 3B+.SLDPRT, port-panel-3b-2p.SLDPRT, port-panel-3b-3p.SLDPRT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]
2022-05-03 Create pro - switch.STL
    [pro - switch.STL]
2022-08-28 fix: pisugar3 case
    [comp3.SLDASM, pisugar3_shell_xl.SLDPRT, pisugar3_shell_xl.STL]
2024-06-06 feat: STEP files for PiSugar3
    [18650x3-box.SLDPRT, Ras Pi 3B+.SLDPRT, batt5000.SLDPRT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]
2024-07-05 update: model for 3.52inch-epaper lid
    [3.52inch-epaper-lid.SLDPRT, 3.52inch-epaper-lid.STEP, 3.52inch-epaper-lid.STL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]
2024-07-09 fix: pro epaper lid
    [3.52inch-epaper-lid.SLDPRT, 3.52inch-epaper-lid.STL]
2024-09-05 [nit] wording fix in README.md
    under "PiSugar Case"
    the entry for the pisugar3 is wrongly named pisugar2
2025-03-03 feat: pisugar step file
    [pisugar2Board.SLDPRT, pisugar2Board.STEP, pisugar3Board.SLDPRT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]
2025-06-20 update: pisugar 3 case
    [RaspberryPiZeroW.SLDPRT, batt-1200.SLDPRT, pisugar3_button.SLDPRT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]
2025-06-20 udpate: pisugar 3 thin shell
    [pisugar3_shell_xl.SLDPRT, pisugar3_thin_shell_xl.SLDPRT, pisugar3_thin_shell_xl.STL]
